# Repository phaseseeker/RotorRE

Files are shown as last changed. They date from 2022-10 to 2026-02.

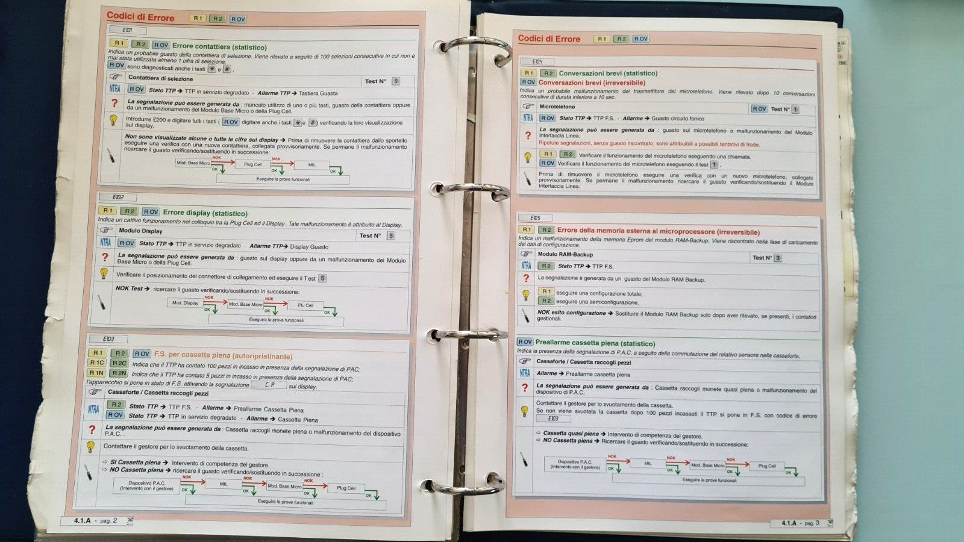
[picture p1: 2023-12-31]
manual/s-l1600 (2).png

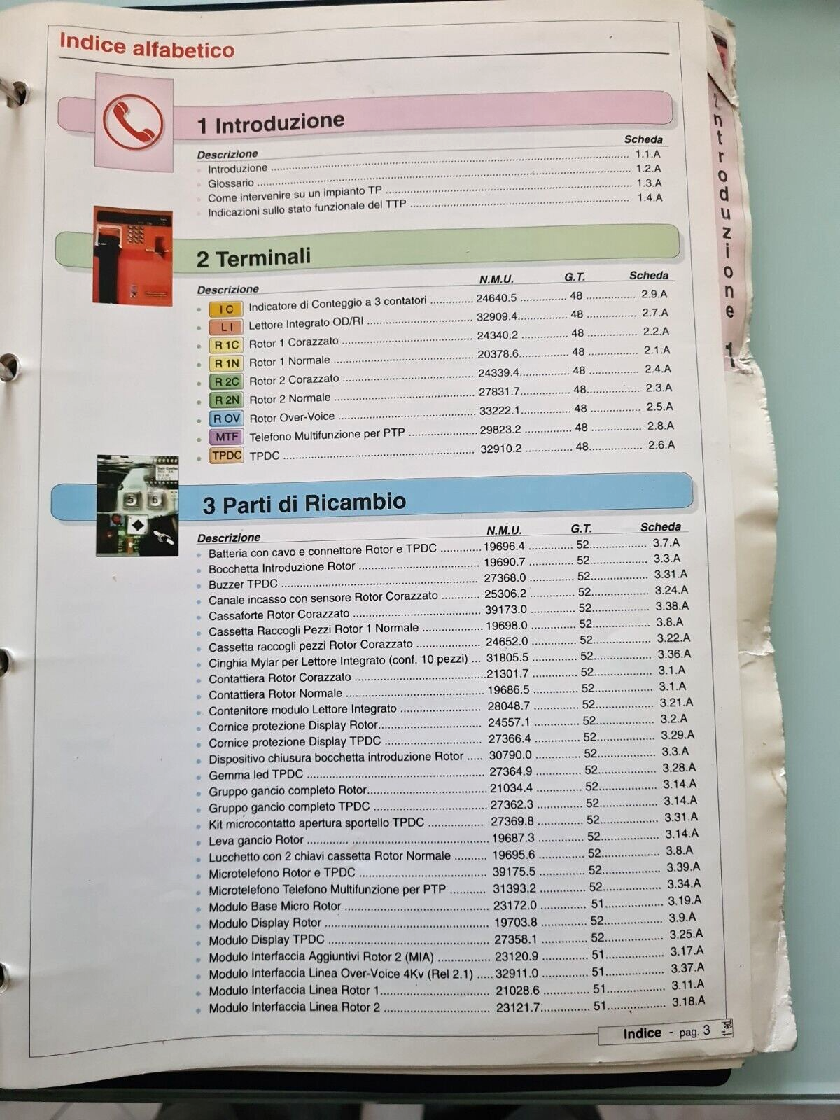
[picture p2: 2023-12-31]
manual/s-l1600 (9).png

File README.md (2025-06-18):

# RotorRE
(versione in italiano più in basso)

Collection of files from my IPM Rotor 2 reverse engineering project
For all the info, see https://hackaday.io/project/181937-reverse-engineering-the-rotor

The "schematics" folder contains schematics for the board I've traced so far. Note that that there are different revisions of some of the boards with minimal differences. The revisions I actually traced are reported in the folders; designators in the files match the designators on the physical board, and as far as I know they should match between revisions.

The "hitachi" folder contains the original manual for the HD6305 processor used in the phone AND the Ghidra module I wrote to decompile the ROMs.

Parts of the original manual can be found in the "manual" folder

There's also some of the pictures I took of the internals in the "pics" folder.

I DO have binary images of the ROMs for the boards I have, both for the phone and for the internal card reader. I won't post them here since it's still technically copyrighted code. All of the phone CPU boards in my possession are equipped with ROM version 1.11 from '91, while my card readers have two different FW revisions. Not 100% of the differences yet. I haven't worked on the newer "OV" revisions board yet and I don't plan to unless I absolutely have to.

-------------------------------------------------------

Collezione di file per il mio progetto di reverse engineering del telefono pubblico italiano Rotor 2 (prodotto da IPM)
La documentazione in ITALIANO è contenuta nei file doc.pdf e documentazione.odt; parte dei manuali ufficiali Telecom/SIP/IPM sono disponibili nella cartella "manual"
Attualmente il progetto è arrivato al punto che è possibile inizializzare il telefono ed utilizzarlo per ricevere/effettuare chiamate, come se fosse un Rotor 1; 
tutte le funzioni "avanzate" quali incasso monete, chiamate con schede ecc non sono ancora disponibili

La cartella "schematics" contiene gli schemi di tutte le schede del Rotor 2 + il lettore di schede ("LIOD") in formato KiCad;
notare che le tre varianti principali del telefono (Rotor 1 "due fili", Rotor 2, Rotor OverVoice) differiscono solo nella scheda di Interfaccia Linea,
mentre le altre schede sono intercambiabili e pressochè identiche. Esiste inoltre una variante solo schede, il Rotor 3 "TPDC", che ha in comune il
solo lettore, ed una variante parecchio rara del Rotor 1 (riconoscibile per il foro della serratura posto in basso a destra); di quest'ultimo sono
disponibili gli schemi originali nella cartella "manual" (in ogni caso le IL dei Rotor 1 e 2 sono abbastanza simili fra loro)
Al momento non ho intenzione di disegnare schemi per le interfaccia linea tipo OV se non assolutamente necessario in quanto sono decisamente più moderne
delle altre e quindi più rognose da analizzare.

La cartella "hitachi" contiene il manuale originale del microcontrollore HD6305 (instruction set Motorola 6805) del telefono, più un modulo per Ghidra.

La cartella "pics" contiene semplicemente alcune foto dell'interno di un Rotor 2.

Sono in possesso delle immagini delle ROM dei micro delle tre varianti del telefono + del lettore (ma non di tutte le revisioni del software), ma NON
le pubblicherò qui dato che tecnicamente si tratta di codice coperto da copyright.

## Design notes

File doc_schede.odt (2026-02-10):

Schede telefoniche

Questo documento descrive nel dettaglio le schede telefoniche prepagate, del tipo a banda magnetica Urmet, rilasciate da SIP e poi Telecom Italia per l’utilizzo con i telefoni pubblici tipo Rotor e G+M.

Premessa

Le informazioni contenute in questo documento sono sia frutto dei lavori precedenti da parte del progetto Magneto (vedi http://magneto.eptousa.altervista.org/) e del progetto “Schedeleaks” (vedi http://schedetelefoniche.org/), che ringrazio, sia di ore di ricerche e di reverse engineering effettuate da me su un lettore di schede originale Urmet tipo LIOD (il lettore utilizzato dai Rotor).

Struttura fisica

Le hanno dimensioni conformi allo standard ISO/IEC 7810 ID-1 (quindi misurano 85,60x53,98mm), con tre importanti differenze:

- Lo spessore è inferiore: 0,35mm contro circa il doppio di una scheda ISO Questo è necessario perché i lettori tradizionali Urmet/IPM sono del tipo “a tamburo” e necessitano di una scheda che sia sufficientemente flessibile per avvolgersi attorno al tamburo gommato del lettore.
- La banda magnetica si trova alla medesima distanza dal centro della carta rispetto ad una scheda ISO, ma è più sottile (circa 8mm) e più corta (anche se esistono schede con lunghezze della banda differenti)
- L’angolo della scheda è preforato e va rimosso prima dell’uso; lo scopo dell’angolo rimovibile è il garantire che una scheda nuova sia effettivamente “vergine” e contenga tutto il suo credito.

Codifica dei dati

Le similarità con le schede “tradizionali” finiscono qui. La codifica dei dati, rimasta per anni un mistero e fonte di grandi curiosità per i phreaker, è infatti completamente nonstandard e proprietaria Urmet.

Un primo indizio ci viene fornito proprio da un brevetto Urmet, codice IT1159459B “Sistema di registrazione e lettura di schede magnetiche valorizzate particolarmente per telefonia pubblica”

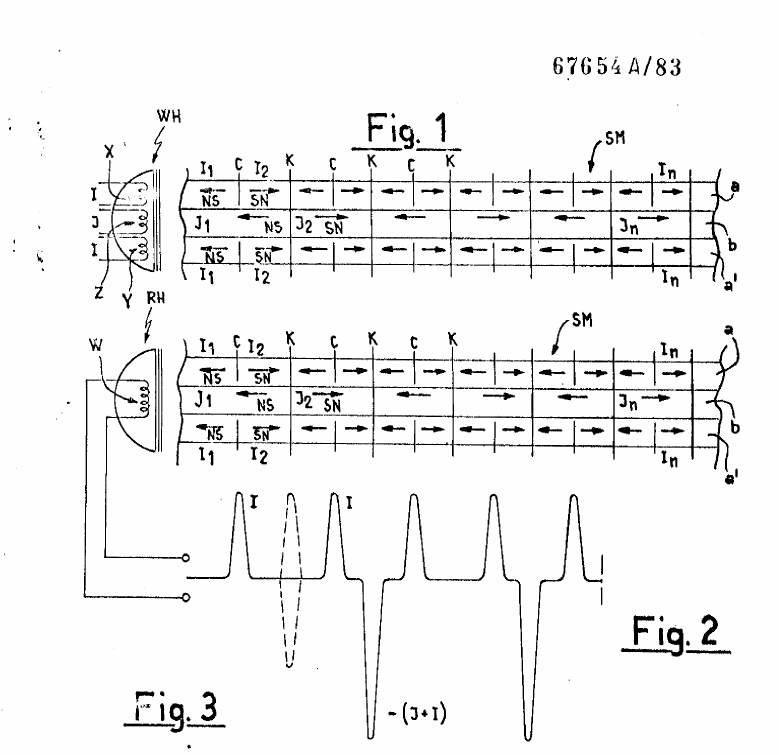
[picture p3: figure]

Come visibile dalla figura, la banda magnetica presenta tre tracce longitudinali:

- Quella centrale costituisce il “clock” della scheda, e permette di sincronizzare il lettore ai dati contenuti
- Le due tracce laterali hanno lo stesso contenuto, e costituiscono i dati effettivamente memorizzati

Questa soluzione, per quanto bizzarra, ha due vantaggi teorici rispetto ad una codifica ISO:

1. La presenza di un clock facilita le operazioni di lettura da parte del lettore, che a questo punto può adattarsi ad un range di velocità di movimento della scheda abbastanza ampio
2. Come da brevetto, dato che testine magnetiche a tre tracce sono sostanzialmente introvabili sul mercato, dovrebbe risultare molto difficile scrivere una scheda contraffatta (nella pratica questo si è rivelato falso, per ragioni non difficili da intuire); la lettura invece è possibile con una normale testina a singola traccia, che restituirà un segnale che è la somma di dati e clock.

Come vedremo più avanti, la codifica effettivamente utilizzata dalle schede in commercio è differente da quanto illustrato nel brevetto ma i due punti fondamentali (banda magnetica a tre tracce, clock e dati separati) rimangono validi e ci aiutano nella decodifica.

Se proviamo a catturare il segnale in uscita dalla testina del lettore, opportunamente amplificato, otteniamo una forma d’onda simile a questa:

Figura 1: Banda magnetica di una scheda "servizi aggiuntivi telefonia"

Notiamo la presenza, come già scoperto anche dai ragazzi del progetto Magneto (e visibile, meno chiaramente, con un lentino magnetico), di una serie di elementi (in ordine da sx):

- Un picco di apertura (rosso)
- La 1a trama (giallo)
- Un picco di separazione (rosso)
- La 2a trama (azzurro) (questa scheda ha una 2a trama incompleta; vedi ulteriori dettagli più avanti)
- La 3a trama (credito, verde)
- Un picco di chiusura (rosso)

Ingrandiamo ora l’inizio dei dati della 1a trama:

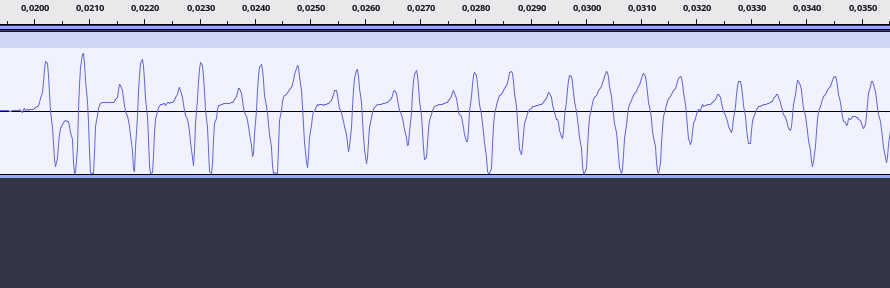
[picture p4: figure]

Figura 2: Prima trama della stessa scheda in fig. 1

Visto così, il segnale non ci dice molto; Avendo a disposizione un lettore originale, però, possiamo ricavare ulteriori informazioni; osserviamo ora i segnali in uscita dal circuito di interfaccia testine (riferiti alla medesima sezione della medesima scheda):

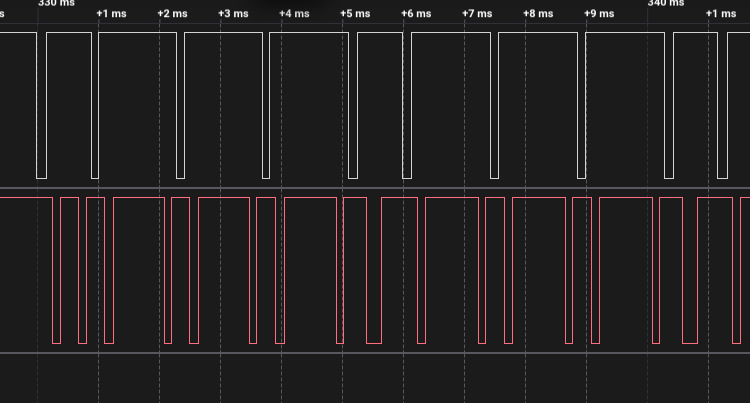
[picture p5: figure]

Figura 3: Inizio della prima trama della scheda in fig.1, separata in clock e dati

La traccia superiore rappresenza il clock estratto dalla scheda; la traccia inferiore invece i dati.

Se seguiamo l’approccio indicato da Schedeleaks, un bit 0 è codificato come un picco sulla traccia dati fra due picchi di clock, mentre un bit 1 è codificato come due picchi; nella seconda immagine quindi i bit rappresentati sono111101110; l’ordine dei dati è big endian.

Confrontando inoltre questi due segnali digitali con la forma d’onda analogica presente sopra, notiamo che dati e clock sono rappresentati tramite picchi con polarità opposta; nel caso specifico della foto il clock corrisponde a picchi positivi mentre i dati a picchi negativi. (la polarità dipende dal modo in cui è collegata la testina; l’aspetto importante è che dati e clock hanno polarità opposte).

I primi due bit contenuti su una scheda sono “speciali”: sono sempre due 1 ed il primo è sempre “corto” (distanza fra i due clock ridotta rispetto ai successivi bit a 1); questi bit NON sono parte dei dati della scheda, ed il lettore misura la durata di entrambi. Sospetto questo sia utilizzato per calibrare la velocità di movimento della scheda.

Analizziamo ora il contenuto delle varie sezioni:

1a trama

Questa trama contiene il numero seriale della scheda telefonica; conosciamo il significato delle singole parti del seriale grazie ai lettori ufficiali SIP (lettore G+M accoppiato ad uno speciale “display”).

La 1a trama è composta da 2 bit speciali + 40 bit di dati:

- I primi due bit, come indicato sopra, sono speciali e non fanno parte del contenuto della scheda
- Byte 0: Checksum, vedi algoritmo più sotto; I primi due bit devono essere sempre 1. Il lettore decodifica questi byte e li memorizza, ma non li invia al Rotor.
- Byte 1: Classe scheda. Intero, unsigned, a 8 bit.
- Byte 2: N° di emissione. Intero, unsigned, a 8 bit. Il numero visualizzato dal lettore corrisponde a (valore del byte + 1)
- Byte 3: N° serie. Intero, unsigned, a 8 bit. Anche qui va aggiunto 1 al valore letto.
- Byte 4 e 5: N° progressivo. Intero, unsigned, a 16 bit (big endian). Anche qui va aggiunto 1 al valore letto.

La verifica del checksum avviene tramite i seguenti passaggi:

1. Si conta il numero totale di bit a ‘1’ all’interno di entrambe le trame escluso il byte di checksum
2. Si calcola quindi il complemento a 1 del valore ottenuto al punto 1 (cioè si fa un NOT bit a bit del valore del contatore)
3. A questo punto si controlla il valore dei bit 7,6 (i due col peso più alto) del checksum letto dalla scheda; questo determina quale di quattro costanti possibili va sommata al valore del punto 2, nello specifico:
  1. Bit 00 → +6
  2. Bit 01 → +5
  3. Bit 10 → +4
  4. Bit 11 → +0
4. Si prende il valore appena ottenuto e si effettua un OR bit-a-bit con la costante 0xC0
5. Il valore appena calcolato deve coincidere con il byte di checksum letto dalla scheda, altrimenti questa viene rifiutata

Il lettore tipo LIOD trasmette sempre il contenuto di questa trama al Rotor, sotto forma di 4 byte (cioè i byte 1-5 della trama). Per la scheda dell’immagine la prima trama è (DD) 1A F1 9C FC

2a trama

Questa trama contiene dati aggiuntivi, utilizzati dal traslatore di centrale (il TRS nella documentazione SIP/Telecom) solo nel caso in cui la scheda riporti del credito.

Il lettore tipo LIOD infatti trasmette il contenuto di questa trama solo per schede non esaurite.

Gli altri documenti sulle schede parlano di due tipi diversi di 2a trama, come visibile sotto (la trama che ci interessa è evidenziata in azzurro):

Figura 4: banda magnetica della scheda di fig.1; notare la 2a trama "spezzata"

Figura 5: banda magnetica di una scheda "dilungatevi pure" con 2a trama "lunga". Forma d'onda presa dai file del progetto Magneto

Come possiamo notare dalle figure, le due schede hanno seconde trame con un numero di bit diverso; sia gli autori del progetto Magneto che quelli del progetto Schedeleaks ipotizzano che si tratti di tipi diversi di scheda telefonica, tuttavia la spiegazione è diversa.

Se proviamo a sovrapporre le bande magnetiche delle due schede, notiamo che in entrambi i casi la lunghezza della trama è simile, ma nel caso della trama “spezzata” sembra che sia stata rimossa una porzione di banda; questo perché è esattamente quel che è accaduto alla prima scheda!

Analizzando il comportamento del lettore, infatti, si scopre che quando una scheda raggiunge 0 unità di credito (come nel caso della prima scheda), il lettore stesso procede a distruggere parte della 2a banda, in modo da essere completamente sicuri che la scheda sia completamente inutilizzabile e non possa essere ricaricata alterando la sezione credito; si tratta di quello che i nostri amiconi della Urmet chiamano obliterazione magnetica.

Una 2a trama intatta contiene esattamente 32 bit di dati.

Il LIOD invia questi 4 byte al telefono solo nel caso in cui la scheda risulti carica; per una scheda con 2a trama obliterata, la lettura si interrompe una volta rilevato il gap dopo i primi 3 bit di dati, e vengono trasmessi al Rotor quattro byte vuoti (0x00)

3a trama: credito

Questa trama contiene semplicemente il credito della scheda, in unità di valore 100L o 0,10€. La lunghezza di questa sezione è variabile, in quanto ciascuna unità è codificata semplicemente come un bit 1, e la banda è sempre terminata con un ulteriore bit 1. Il credito, quindi, è pari al numero di bit memorizzati in questa sezione – 1.

Man mano che la scheda viene utilizzata, il lettore procede a cancellare parti di questa sezione per alterarne il valore.

N.B: Il valore di credito memorizzato sulla scheda è “preso per buono” solamente nei telefoni tipo G+M; i telefoni tipo Rotor (e Digito) inviano seriale + 2a trama + credito letto dalla scheda al traslatore di centrale, il quale consulta un database remoto con i dati di credito delle schede e comunica al telefono eventuali incongruenze. Pertanto, quando queste schede erano “in servizio”, anche se fossimo riusciti a riscrivere il contenuto della sezione credito (cosa che è stato dimostrato essere possibile), comunque non sarebbe stato possibile ingannare il telefono.

In ogni caso non è possibile riutilizzare una scheda che sia completamente scarica, in quanto la 2a banda risulterebbe danneggiata.

Il LIOD trasmette il credito al telefono sotto forma di un singolo byte.

La trasmissione completa LIOD → Rotor ha quindi la seguente struttura:

03 PP PP PP PP SS SS SS SS CC CK

Dove:

- 03 è il tipo di scheda (→ “Prepagata telefonica”)
- PP identifica un byte della 1a trama
- SS identifica un byte della 2a trama
- CC è il credito (in unità)
- CK è il checksum generato dal lettore. Si tratta dello XOR di tutti i byte precedenti (NON è il checksum contenuto sulla banda magnetica!)

Extra: carte di credito telefoniche

Una carta di credito telefonica (CTC) è semplicemente una carta di credito rilasciata da SIP/Telecom ed utilizzata esclusivamente per telefonare. Queste carte richiedono un PIN di 4 cifre (indicato come “codice utente”), verificato sempre dal traslatore, per autorizzare la transazione.

In questo caso la codifica utilizzata è quella standard ISO, anche se la quantità di dati presente è inferiore rispetto ad una carta di credito “commerciale”.

Esempio del contenuto di una scheda: ;977887:8739:8239? (scheda di test SIP)

Il tipo scheda associato ad una CTC è 04.

Il LIOD invia sempre 11 byte, di cui il primo è appunto 04 e l’ultimo è il checksum XOR.

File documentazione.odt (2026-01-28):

Documentazione Rotor

SCL1054-V4

Tre funzioni: port expander (1 porta bidirezionale, 2 solo output + 1 singolo pin per selezione banco ROM), espansione RAM (192 byte extra) e logica decodifica indirizzi.

La RAM è mappata nel range di indirizzi 0x0144-0x1FF ed è accessibile come fosse RAM interna al micro

Le porte I/O sono controllate tramite 5 registri mappati in memoria (i nomi corrispondono a quelli usati nel disassembly del codice):

1. SCL_DATA: bidirezionale; registro “direzione” @ 0x0023 (bit a 1 → il pin è configurato come output), registro dati @ 0x0022. Porta a 8 bit, prende il nome di “SCL_DATA” perché, come visibile dagli schemi, funge da bus dati esterno per le varie periferiche collegate al SCL
2. SCL_ADDR: 8 bit, output only; registro dati @ 0x0020. Pilota, tramite U5 e U6 il bus indirizzi di ROM/RAM esterne. I bit 7, 6, 5, 3 sono multiplexati con i segnali di controllo dei tre solenoidi + il reset del LCD (vedi schema)
3. SCL_CTRL: 8 bit, output only; registro dati @ 0x0021. Collezione di vari output, controlla lo schema per più dettagli. (Nello schema, i pin di questa porta sono indicati come SCL-nn, dove nn è il numero del pin nel package del SCL; SCL-43 corrisponde al bit 0, e gli altri seguono in ordine crescente)
4. SCL_BANK: 1 bit, output only; Pilota A14 sulla ROM: permette quindi di scegliere fra i due banchi di codice.

Tutta la logica di decodifica degli indirizzi di memoria per le porte, la RAM e la ROM, è contenuta nell’SCL, che procede a selezionare automaticamente i circuiti corrispondenti.

Comunicazione dati

Il Rotor comunica con il “traslatore di centrale” (di seguito indicato semplicemente come TRS) utilizzando la linea as/bs, dalla quale viene anche prelevata la corrente necessaria per l’alimentazione del circuito caricabatterie.

Le comunicazioni in direzione TRS→Rotor avvengono invertendo la polarità della linea di segnalazione (polarità normale: filo a NEGATIVO, filo b POSITIVO; N.B: i sistemi telefonici sono a TERRA POSITIVA, quindi è il filo B ad essere a terra) in modo temporizzato; queste inversioni vengono rilevate dal telefono mediante il fotoaccoppiatore OP3.

Le comunicazioni in direzione Rotor→TRS avvengono invece variando la corrente assorbita dal telefono sulla linea di segnalazione: quando il telefono desidera trasmettere, il fotoaccoppiatore OP4 viene attivato, cortocircuitando i tre transistor T5,T6,T7 e aumentando la corrente di linea; il TRS rileva questa variazione mediante un proprio fotoaccoppiatore inserito in serie alla linea.

Nota: questo tipo di comunicazione è stato “ereditato” dal precedente telefono modello G+M, tant’è che nel brevetto di uno dei TRS compatibili con il Rotor il circuito di interfaccia è indicato con il nome di SGM (“Sonda Gettone+Moneta”)

Esistono due diversi “protocolli” di comunicazione, utilizzati in situazioni differenti:

1) Protocollo “Telegrafico”:

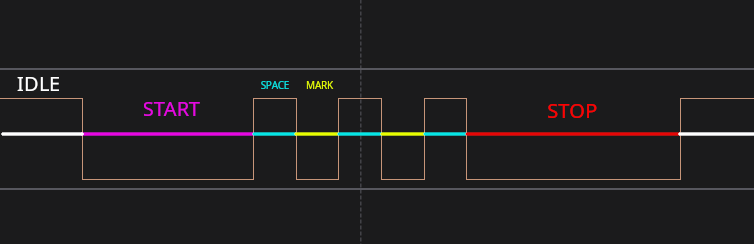
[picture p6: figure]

Si tratta del più semplice dei due, ed è simile alla selezione decadica; una comunicazione di questo tipo si può analizzare dividendola in 5 fasi, come visibile nell’immagine.

N.B: I segnali sono mostrati nella forma in cui appaiono sulle porte di I/O del microcontrollore. I segnali in entrambe le direzioni (Rotor→TRS e TRS→Rotor) assumono in questo caso lo stesso aspetto in termini di forme d’onda.

Per i segnali provenienti dal TRS, il livello logico ALTO corrisponde a polarità normale, mentre quello basso a polarità invertita; per i segnali provenienti dal Rotor, il livello ALTO corrisponde a OP4 off e quindi corrente di linea minima (la sola corrente di alimentazione), mentre quello basso corrisponde a OP4 on e corrente massima

A. IDLE: linea “a riposo”
B. START: impulso di inizio comunicazione. Per le trasmissioni provenienti dal Rotor, ha due possibili durate; Per le comunicazioni in direzione TRS→Rotor, diversi valori per lo start sono ammessi, vedi più sotto per i dettagli
C. SPACE, MARK: In seguito all’impulso di start, i dati da trasmettere sono inviati cifra (decimale) per cifra sotto forma di una serie di impulsi negativi (mark), lunghi 10ms, separati da pause della stessa lunghezza (space). La cifra trasmessa è pari al numero di mark + 1; lo 0 è trasmesso sotto forma di 10 impulsi.
D. STOP: impulso di fine trasmissione. Ha sempre durata 50ms in direzione Rotor→TRS, mentre in direzione opposta sono ammesse due differenti lunghezze che, di nuovo, cambiano il modo in cui vengono interpretati i dati trasmessi; vedi sotto per i dettagli

Tipi di trasmissioni telegrafiche

DIREZIONE TRS → Rotor

1) Comando: start 50ms, stop 50ms

Il telefono interpreta il numero inviato come indice del comando da eseguire. Sono supportati 7 comandi, descritti più avanti in questo documento. Se il numero di impulsi risulta > 7, la trasmissione viene semplicemente ignorata

2) Addebito monete: start 35ms, stop 50ms

Comando di “addebito” per il credito relativo alle monete (il credito “monete” ed il credito “carte” sono gestiti in modo completamente separato all’interno del software del telefono)

Il telefono sottrae una somma pari a cifra_inviata*100L al credito e visualizza il nuovo credito

NOTA: Per le transazioni a monete, è sempre necessaria una successiva conferma di incasso, altrimenti il telefono restituisce la moneta.

NOTA 2: Prima di inviare un comando di addebito, è necessario inviare almeno una richiesta credito al telefono, vedi l’elenco comandi più in basso, altrimenti l’incasso non andrà a buon fine

3) Addebito schede: start 20ms, stop 50ms

Comando di “addebito” per le schede telefoniche. Il telefono sottrae una somma pari a cifra_inviata*100L al credito, visualizza il nuovo credito e aggiorna il credito sulla banda magnetica della scheda.

NOTA: In questo caso non è necessaria una conferma di incasso, il lettore integrato cancella il credito non appena il comando è ricevuto.

NOTA 2: Se il telefono riceve questo comando quando non è presente una scheda e/o non è presente nessun lettore, la cifra ricevuta viene visualizzata sul LCD, fino ad un massimo di 4 cifre contemporaneamente (10 impulsi = “0”; i valori da 11 a 15 corrispondono a simboli)

4) Telereset Rotor: start 700ms, stop 50ms

Permette al TRS di reinizializzare il Rotor; Il telefono si pone in FS e attende una nuova configurazione.

NOTA: non si tratta di un vero e proprio reset, in quanto il software si limita a cancellare la configurazione in memoria

5) Possibile telereset LIOD: 70ms < start < 700ms

Alla ricezione di questa trasmissione, il telefono resetta una serie di variabili relative allo stato del LIOD; ulteriori indagini sono necessarie

6) Incasso monete: start 50ms, stop 90ms

Comando di incasso/conferma addebito per le monete: conferma la riduzione del credito effettuata dai comandi di addebito. La cifra inviata può avere valore 1-3, altrimenti il comando viene ignorato. Dalle prove effettuate sembra che solo il valore 2 venga accettato.

NOTA: Come specificato per il comando di addebito, l’incasso può avvenire solo se il credito (inteso come il numero ed il tipo di monete inserite) è stato inviato dal telefono al TRS

DIREZIONE ROTOR → TRS

1) Comunicazione generica: start 40ms, stop 50ms

Utilizzata dal telefono quando deve inviare informazioni al TRS, sia che si tratti di risposte a comandi (eccetto comando “richiesta credito”) sia che si tratti di allarmi (trasmissioni “spontanee”). In questo caso il telefono invia una singola cifra.

2) Conferma incasso: start ??, stop 50ms

Come sopra, ma utilizzata per confermare la ricezione con successo del comando di incasso. La cifra inviata dal telefono corrisponde a quella che era stata inviata dal TRS all’interno del comando di incasso. In caso di incasso non riuscito, non si riceve nessuna risposta dal telefono.

NOTA: A differenza dei telefoni precedenti, nel Rotor 2 la conferma di incasso NON avviene necessariamente quando la moneta transita davanti al sensore posto alla fine del canale di incasso; è sufficiente che il telefono abbia registrato la richiesta per ottenere la conferma incasso.

3) Credito: start 40ms ripetuti (vedi foto), stop 50ms

Tipo di trasmissione utilizzato per comunicare al TRS il credito IN MONETE inserito nel telefono; si tratta di tre cifre inviate una di seguito all’altra, separate da uno “start” da 40ms inviato dopo gli impulsi della 1a e 2a cifra.

La 1a cifra ha valore 200L, la 2a ha valore 100L, la 3a è sempre 0.

NOTA: Il telefono non invia mai più di 14 impulsi per la 1a cifra e 6 per la 2a.. In caso di credito superiore a 3400L, quindi, il valore ricevuto può non rispecchiare il credito effettivamente presente nel tamburo.

NOTA 2: Il telefono risponde al comando di richiesta credito solamente la 1a volta che lo riceve all’interno di una conversazione. Per le monete inserite successivamente, il telefono invia in modo spontaneo altre 3 cifre che indicano il credito aggiunto (quindi non il totale, ma solo quello relativo alle monete appena inserite).

4) Segnalazioni “spontanee”/allarmi: start 40ms, stop 50ms

Il formato è esattamente lo stesso delle comunicazioni generiche, ma in questo caso si tratta di dati inviati dal telefono senza che il TRS invii alcuna richiesta. Si tratta anche qui di una “cifra” sola, e i valori noti sono:

- 10 → Cornetta riappesa
- 11 → Interruzione colloquio con lettore interno (guasto MIA, rimozione lettore ecc)
- 12 → Sconosciuto
- 13 → Cassaforte aperta (solo Corazzato)
- 14 → Cassetta monete rimossa (solo Corazzato)
- 15 → Perdita linea voce

2) Protocollo “pseudo-BPSK”

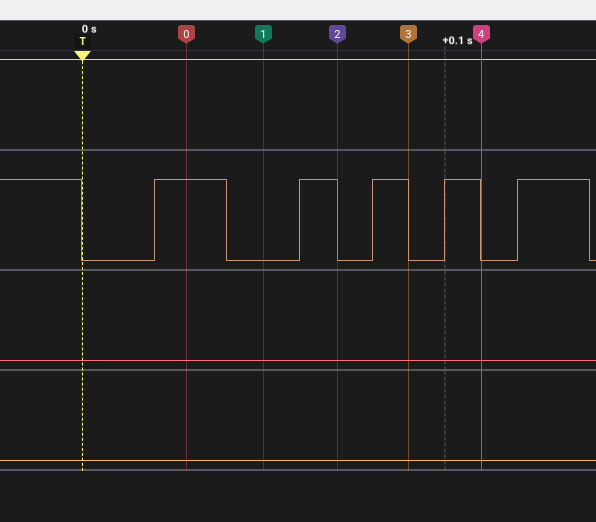
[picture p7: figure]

Si tratta del secondo protocollo supportato, utilizzato principalmente per inviare i dati di carte di credito (telefoniche e/o “commerciali” di tipo Diners e AMEX) e schede telefoniche prepagate.

In questo caso la trasmissione è di tipo binario e, da quanto determinato finora, sembra sia utilizzata solo in direzione Rotor → TRS

La trasmissione con questo protocollo inizia sempre con uno start, composto da un picco negativo lungo 20ms seguito da 10ms di pausa (nella foto, è la parte fra il cursore T ed il cursore 0), seguito poi dai dati binari.

Tali dati sono codificati con quella che possiamo definire codifica pseudo-BPSK (Binary Phase Shift Keying):

- Un bit a 0 è codificato come 10ms a livello alto seguiti da 10ms a livello basso
- Un bit a 1 è codificato come 10ms a livello basso seguiti da 10ms a livello alto

Nella foto di esempio, i primi 4 bit trasmessi sono 0111 (→ 0x7)

Comunicazione lettore-Rotor:

Come molti aspetti di questo telefono, la comunicazione fra lettore di schede interno (d’ora in poi indicato come LIOD, “Lettore Integrato a Obliterazione Durante”, come viene chiamato nei manuali) avviene in modo assolutamente non standard.

A livello elettrico, la comunicazione avviene tramite due linee unidirezionali; d’ora in poi indicheremo come TXD la linea che sposta dati in direzione Rotor→LIOD e RXD quella in direzione opposta

(N.B: nello schema le linee sono indicate dal punto di vista del LIOD, quindi invertite rispetto a questo documento).

Un’ulteriore linea viene utilizzata dal telefono per rilevare la presenza del lettore; un resistore di pull’up all’interno del lettore fa sì che questa linea sia a +5V con lettore presente, 0 altrimenti.

Nota: La scheda di interfaccia lettore (indicata d’ora in poi come MIA, “Modulo Interfaccia Aggiuntivi”, di nuovo per coerenza con il manuale) è decisamente più complicata di quanto necessario in quanto è concepita per supportare due differenti tipi di lettore.

Non sappiamo di per certo quale sia il secondo lettore teoricamente supportato (la documentazione lo indica semplicemente come lettore di debito, ma il manuale, almeno la versione più recente, indica che l’unico lettore effettivamente utilizzato è il LIOD); un’ipotesi è che si tratti del mitico “lettore azzurro”, un lettore di schede telefoniche progettato per l’uso con il G+M e prodotto in numeri molto ridotti, ma non dispongo di un lettore per confermare questa ipotesi e non sappiamo nemmeno se il codice lato Rotor sia completo e funzionante.

Un ulteriore pin del microcontrollore viene utilizzato per scegliere fra i due e l’interfaccia per l’altro lettore utilizza dei pin in più, ma per semplicità ignoreremo completamente questa prossibilità.

Tutte le foto e le descrizioni da qui in poi fanno riferimento ai segnali come visti dal microcontrollore del Rotor. In ogni caso, una volta che il telefono è inizializzato ed ha rilevato correttamente il lettore, il MIA passa il segnale RXD (e DET) inalterato dal lettore al telefono, mentre TXD viene invertito.

Il successivo Rotor O.V. fa a meno del MIA e controlla il lettore direttamente dal micro.

Nota 2: Esistono diverse revisioni del LIOD, l’ultima delle quali viene indicata nel manuale come LI O.D./R.I (“Lettore Integrato a Obliterazione Durante e Restituzione dalla bocchetta di Ingresso). Il manuale fornisce ulteriori dettagli a tale proposito; l’interfaccia rimane la medesima.

Il protocollo di comunicazione non è né RS232 standard, né tanto meno una delle interfacce sincrone “comuni” quali SPI, I2C ecc.

Il Rotor agisce sempre come master della comunicazione, in quanto il lettore non può iniziare una comunicazione ma solo inviare dati quando clockato dal telefono.

Vediamo un esempio di una comunicazione:

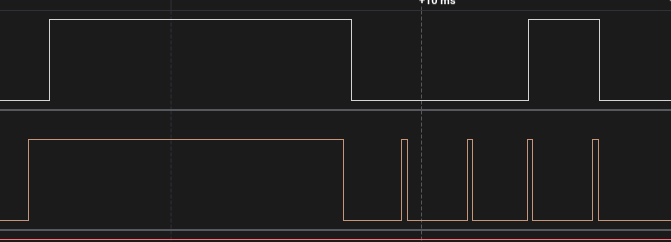
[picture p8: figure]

In bianco RXD, in arancio TXD; TXD, come intuibile dall’immagine, ha la doppia funzione di trasportare comandi in direzione Rotor→LIOD e di clockare il lettore per la risposta.

La comunicazione si articola in due fasi:

1. Comando: (sempre proveniente dal telefono e destinato al lettore) si tratta del primo impulso positivo; I differenti comandi sono codificati variando la lunghezza di tale impulso. Il firmware del Rotor 2 versione 1.4, l’ultima rilasciata, supporta 10 comandi; il lettore è in grado tuttavia di riconoscerne un numero più ampio (potrebbero essere comandi di test/comandi avanzati supportati solo dal Rotor OV). Il lettore risponde semplicemente pilotando RXD allo stesso livello di TXD (salvo casi particolari indicati più avanti)
2. Clock + risposta: Il telefono a questo punto procede a clockare il lettore in modo da leggere la risposta inviata da quest’ultimo. Ciascuno dei quattro impulsi di clock inviati dal telefono ha entrambi i fronti attivi: RXD viene campionato quindi due volte per impulso, una sul fronte di salita ed una sul fronte di discesa, con un piccolo delay fra il fronte di clock ed il campionamento per consentire al lettore di pilotare RXD al valore appropriato. Gli impulsi di clock sono lunghi circa 250 us, separati fra loro e dal comando da una pausa di 2,5 ms.

Nella trasmissione di esempio, il telefono invia il comando “di idle” (comando che viene inviato continuamente dal telefono per segnalare al lettore che è tutto ok e può accettare schede), mentre il lettore risponde con 0x07.

Esiste una modalità di trasmissione particolare, che chiameremo burst mode, utilizzata per la lettura delle schede e per alcuni comandi particolari. In questa modalità, dopo aver letto il primo byte di risposta al comando, il Rotor non riporta la linea a riposo ma, ad una distanza circa 5 ms (il timing non è critico: pause molto più lunghe sono accettabili), ripete altri 4 clock per un totale di 40 impulsi, leggendo cioè 10 byte oltre quello iniziale.

La durata del burst è fissa a 10 byte.

Esiste, come accennato sopra, un caso particolare: nel caso in cui il lettore sia occupato a leggere una scheda, si comporta come visibile al centro della foto seguente:

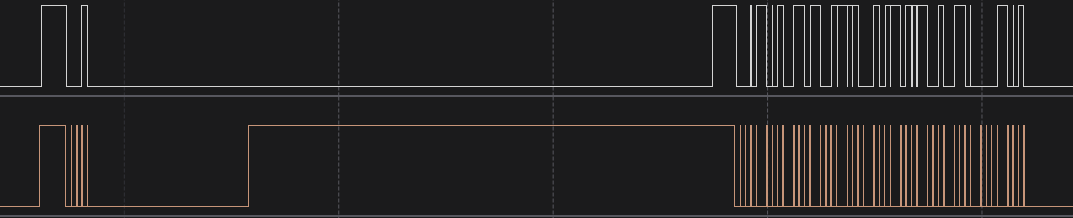
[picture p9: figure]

Il lettore, cioè, rilevato l’inizio del comando, non risponde portando RXD a livello alto (quasi) istantaneamente, come di consueto, ma lo fa solo una volta terminata la lettura. In questo caso la durata del comando è misurata a partire dal rising edge di RXD

Una lettura avvenuta con successo porta ad una differente risposta al comando di IDLE (più dettagli sulle risposte in seguito), seguito dai dati delle schede trasmessi in burst mode.

Comandi e risposte lettore:

Le durate dei comandi, per il firmware lettore v3.1 04/05/93, sono:

- 0ms < len <= 2ms CMD0: NOP
- 2ms < len <= 17ms CMD1: Stato lettore/IDLE
- 17ms < len <= 32ms CMD2: Possibile comando di addebito
- 32ms < len <= 47ms CMD3: Sconosciuto
- 47ms < len <= 62ms CMD4: Espulsione scheda
- 62ms < len <= 87ms CMD5: Modalità Rotor (necessario per il normale funzionamento)
- 87ms < len <= 102ms CMD6: Reinvia dati scheda*
- 102ms < len <= 117ms CMD7: Richiesta dati extra CCC *(ulteriori 10 byte)
- 117ms < len <= 132ms CMD8: Sconosciuto
- 132ms < len <= 147ms CMD9: NOP
- 147ms < len <= 162ms CMD10: Sconosciuto
- 162ms < len <= 177ms CMD11: Sconosciuto
- 177ms < len <= 195ms CMD12: Sconosciuto
- 195ms < len <= 207ms CMD13: NOP
- 207ms < len <= 222ms CMD14: Sconosciuto
- 222ms < len <= 237ms CMD15: Sconosciuto, possibile reset errori meccanica.
- 237ms < len <= 252ms CMD16: Richiesta versione firmware*
- len > 252ms NESSUN COMANDO

I comandi seguiti da un asterisco richiedono l’uso del burst mode. I comandi indicati come NOP non hanno effetto.

Ulteriori dettagli in seguito:

- CMD4: Espulsione scheda. Espelle un’eventuale CTP trattenuta nell tamburo del lettore. Per le CC (commerciali o telefoniche) è necessario inviare un comando di espulsione prima di poter leggere un’altra scheda, nonostante le CC non siano fisicamente trattenute dal lettore.
- CMD5: Modalità “Rotor”. Non si sa quale sia la modalità di default, ma i dati delle schede appaiono corretti solo dopo aver eseguito questo comando.
- CMD6: Ripetizione dati scheda. Il telefono reinvia i primi 10 byte del buffer schede, oppure 10 byte nulli se non c’è nessuna scheda presente. Richiede burst mode.
- CMD7: Richiesta ulteriori dati CCC. Una carta di credito “commerciale” (Diners/AMEX nello specifico, ma il lettore accetta qualsiasi scheda ISO) contiene più di 10 byte di dati; questo comando permette di richiedere gli ulteriori 10 byte. Richiede burst mode, NON contiene checksum
- CMD16: Richiesta versione firmware lettore. Invia 10 byte in burst mode, codificati BCD; i primi 2 corrispondono alla revisione software (es: 0x03 0x01 → 3.1), i successivi tre la data di rilascio (0x04 0x05 0x93 → 4/5/1993). Termina con un checksum XOR dei 10 byte precedenti (risposta al comando + 10 byte di dati)

Analizziamo ora le risposte. È importante notare che per risposta si intende il byte inviato dal lettore appena ricevuto il comando; per i comandi che fanno uso di burst mode, quindi, i byte ricevuti sono 1+10, cioè 1 di risposta + 10 di dati.

Le risposte, almeno per questa versione del FW, sono univoche: quindi ciascuna risposta è specifica ad un determinato comando.

Risposte conosciute:

- 0x07 Lettore OK. Inviata dal comando di richiesta stato per confermare che il lettore è funzionante e pronto.
- 0x03 Seguono dati CTP. Indica la corretta lettura di una scheda telefonica prepagata; inviato in risposta a CMD1, attiva burst mode ed è seguito da 10 byte nel formato PP PP PP PP SS SS SS SS CC CK, cioè 4 byte della 1a trama + 4 byte della 2a trama + 1 byte credito (in unità) + 1 byte checksum che è lo XOR dei 10 precedenti (quindi incluso lo 0x3). La 2a trama è pari a una serie di 0x00 se la scheda è scarica; ulteriori dettagli nel documento sulle schede
- 0x04 Seguono dati CTC. Indica la corretta lettura di una carta di credito telefonica; inviato in risposta a CMD1, è seguito da 9 byte di dati della banda magnetica + 1 byte di checksum, che è di nuovo lo XOR dei 10 precedenti.
- 0x11 Seguono dati CCC. Inviato come risposta a CMD1, indica la corretta lettura di una CCC (Carta di Credito Commerciale) inserita dall’utente. Attiva burst mode ed è seguita da 10 byte di dati letti dalla banda magnetica e nessun checksum. Per una CCC è necessario richiedere separatamente gli altri 10 byte di dati, vedi sopra.
- 0x0A Richiesta espulsione ricevuta. Indica la ricezione del CMD4. Per una CTP NON è sufficiente a garantire che la scheda sia stata meccanicamente espulsa dal tamburo.
- 0x0C Modalità Rotor attivata. Risposta al CMD5, conferma l’esecuzione del comando.
- 0x0E Seguono dati extra CCC. Inviata come risposta al CMD7, provoca l’attivazione del burst mode; è seguita da 10 byte di dati della scheda. Come specificato prima, per le CCC NON c’è checksum
- 0x13 Segue versione FW. Inviata come risposta al CMD16, attiva burst mode ed è seguita da 9 byte di versione + 1 di checksum, che è 0x13 XOR i 9 byte successivi
- 0x47 CTP espulsa. Conferma l’espulsione meccanica di una CTP; inviato in risposta a CMD1, può essere inviato anche senza che il telefono abbia richiesto l’espulsione della scheda, come nel caso di una scheda scarica o non valida.
- 0xEE Risposta a CMD15, conferma l’esecuzione del comando.

Sequenza di boot del telefono:

Il telefono, per funzionare correttamente, richiede due cose:

1. Batteria tampone principale (6V piombo) sufficientemente carica.
2. Configurazione esterna e contatori gestionali (contenuti nella RAM sulla board “RAM esterna”) validi

La batteria tampone della RAM esterna, che consente al telefono di mantenere configurazione esterna e contatori gestionali memorizzati anche con batteria tampone principale scarica, non è strettamente necessaria per il funzionamento del telefono.

Se la condizione numero 2 è verificata, il telefono può essere avviato in modalità normale (entrambi i dipswitch accanto al display su off) semplicemente premendo reset; terminato il boot, il telefono visualizza F.S. (con LED di “fuori servizio” spento) e si pone in attesa della configurazione remota dal TRS

Altrimenti, se i dati di configurazione non sono validi (ad es. telefono con batterie scariche appena rimesso in servizio), è necessario avviare il telefono con il microswitch di configurazione (il sx, vedi manuale) in posizione ON; questo riscriverà la configurazione in RAM.

Se, inoltre, i contatori gestionali (totale monete in cassaforte ecc) risultano non validi, è necessario avviare il telefono tenendo premuto (dal reset fino all’avvio completo) il pulsante del gestore, che è il pulsantino posto all’interno dello scomparto della cassaforte, visibile con cassetta rimossa.

Sequenza di configurazione remota:

Il telefono, dopo ogni boot avvenuto con successo, si pone in F.S. in attesa della configurazione remota; la procedura in questione è piuttosto semplice, ed è visibile nell’immagine seguente

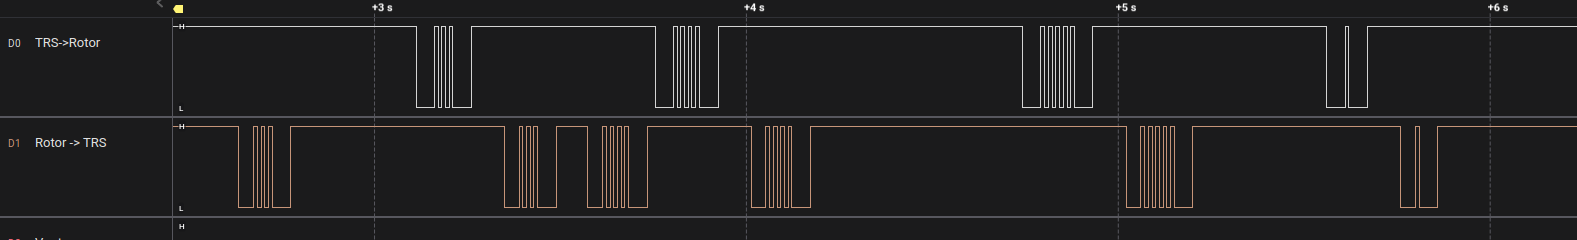
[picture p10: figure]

(riferita ad un telefono con LIOD installato e funzionante).

La procedura prevede la seguente sequenza (tutta eseguita usando il metodo di configurazione telegrafico):

1. Il telefono invia un 3 (prima cifra dello “stato lettore” visualizzato sul display all’avvio, cioè “30”, “33” o “34”, vedi manuale)
2. Il TRS risponde con un 3
3. Il telefono ripete il 3 precedente, quindi invia subito la seconda cifra dello stato lettore (in questo caso 4, lettore OK); Se il lettore è assente (“30” visualizzato sul display all’avvio), questo passaggio ed i due successivi vengono ignorati
4. Il TRS risponde ripetendo l’ultima cifra ricevuta e solo l’ultima (qui un 4)
5. Il telefono ripete la cifra appena ricevuta dal TRS (di nuovo 4)
6. Il TRS ora invia 5 (valore fisso hardcoded)
7. Il telefono risponde 5
8. Il TRS invia 1 (di nuovo un valore fisso)
9. Il telefono risponde 1
10. Il TRS invia quindi, una per una, le tre cifre corrispondenti al valore in lire del gettone telefonico (lo 0 è inviato con 10 impulsi); dopo ogni cifra il telefono risponde reinviando la cifra appena ricevuta al TRS.
11. La procedura di configurazione è ora conclusa ed il telefono è ora funzionante

Nota 1 sul punto 10: la prima cifra del costo del gettone non può essere 0

Nota 2 sul punto 10: a causa di un bug del codice, anche se il telefono può teoricamente accettare qualsiasi valore per le ultime due cifre del costo gettone (es: 123 lire, 488 lire ecc), solo valori multipli di 100 sono effettivamente validi (nello specifico, le ultime due cifre sono salvate in memoria, ma in diversi punti il codice è scritto partendo dal presupposto che il costo sia multiplo di 100 lire e quindi tali cifre sono ignorate)

Una volta terminata la configurazione iniziale, il telefono risulta funzionante e non necessita di ulteriori comunicazioni col TRS per essere utilizzato come un normale telefono. Si comporta sostanzialmente come un Rotor 1: non incassa monete, ma permette di effettuare e ricevere telefonate. Per le altre funzioni (incasso monete, telefonate con schede ecc) è necessario inviare uno o più dei comandi elencati di seguito:

Comandi TRS:

Informazioni note al momento:

- 1 → Lampeggio display. Possibilmente usato come “avviso ottico fine incasso” come per manuale.
- 2 → Conferma validità scheda telefonica; inviato dal TRS dopo aver ricevuto seriale+credito della scheda telefonica per confermare la sua validità e la correttezza del credito contenuto sulla manda magnetica. Nessuna risposta dal telefono.
- 3 → Azzeramento credito schede. Azzera il credito memorizzato dal telefono per quanto riguarda le schede (il credito per le schede e per le monete sono memorizzati separatamente). Se è presente una scheda nel lettore, questa viene espulsa senza alterare la banda magnetica
  Nessuna risposta dal telefono
- 4 → Azzeramento addebiti schede. Azzera eventuali addebiti per le schede che sono stati ricevuti dal telefono ma non processati.
- 5 → Richiesta credito monete. Il telefono invia il credito presente (vedi sopra per il formato)
- 6 → NOP. Al momento non si conoscono ulteriori effetti.
- 7 → Richiesta errori. Il telefono può rispondere con:

1 → Tutto ok.

3 → Guasto sezione monete

4, 5, 9 → Sconosciuti. Probabilmente errori relativi al LIOD.

NOTA: Per ragioni ignote, i codici di errore riportati sopra (incluso quello relativo alla sezione monete) vengono trasmessi SOLO se il lettore è presente. Un telefono privo di lettore risponde sempre “1” anche con sezione monetaria guasta.

La ricezione di un qualsiasi comando provoca un interrupt, eventualmente “svegliando” il micro dallo stato di standby. In presenza di un FS (non irreversibile) attivo, il telefono effettua un autotest.

Se il Rotor riceve un comando in chiamata, quando la cornetta viene riappesa il telefono trasmette 10 (vedi sezione “allarmi” più sopra per ulteriori segnalazioni spontanee)

Note varie:

Importante: se il lettore legge ed accetta una scheda prepagata (quindi una scheda leggibile e con credito != 0), questa viene trattenuta dal telefono in attesa di risposta dal TRS. Per riottenere indietro la scheda NON resettare il telefono: questo ne causa la cancellazione!! (come misura di sicurezza contro truffe con le schede). Il metodo corretto è di inviare un 3 da un TRS simulato, oppure disconnettere la linea telefonica di segnalazione, ed aspettare poi che il telefono invii al LIOD il comando di espulsione scheda.

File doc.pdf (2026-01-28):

# Documentazione Rotor

SCL1054-V4

Tre funzioni: port expander (1 porta bidirezionale, 2 solo output + 1 singolo pin per selezione banco ROM), espansione RAM (192 byte extra) e logica decodifica indirizzi.

La RAM è mappata nel range di indirizzi 0x0144-0x1FF ed è accessibile come fosse RAM interna al micro

Le porte I/O sono controllate tramite 5 registri mappati in memoria (i nomi corrispondono a quelli usati nel disassembly del codice):
1. SCL_DATA: bidirezionale; registro “direzione” @ 0x0023 (bit a 1 → il pin è configurato come output), registro dati @ 0x0022. Porta a 8 bit, prende il nome di “SCL_DATA” perché, come visibile dagli schemi, funge da bus dati esterno per le varie periferiche collegate al SCL
2. SCL_ADDR: 8 bit, output only; registro dati @ 0x0020. Pilota, tramite U5 e U6 il bus indirizzi di ROM/RAM esterne. I bit 7, 6, 5, 3 sono multiplexati con i segnali di controllo dei tre solenoidi + il reset del LCD (vedi schema)
3. SCL_CTRL: 8 bit, output only; registro dati @ 0x0021. Collezione di vari output, controlla lo schema per più dettagli. (Nello schema, i pin di questa porta sono indicati come SCL-nn, dove nn è il numero del pin nel package del SCL; SCL-43 corrisponde al bit 0, e gli altri seguono in ordine crescente)
4. SCL_BANK: 1 bit, output only; Pilota A14 sulla ROM: permette quindi di scegliere fra i due banchi di codice.

Tutta la logica di decodifica degli indirizzi di memoria per le porte, la RAM e la ROM, è contenuta nell’SCL, che procede a selezionare automaticamente i circuiti corrispondenti.

Comunicazione dati

Il Rotor comunica con il “traslatore di centrale” (di seguito indicato semplicemente come TRS) utilizzando la linea as/bs, dalla quale viene anche prelevata la corrente necessaria per l’alimentazione del circuito caricabatterie.

Le comunicazioni in direzione TRS→Rotor avvengono invertendo la polarità della linea di segnalazione (polarità normale: filo a NEGATIVO, filo b POSITIVO; N.B: i sistemi telefonici sono a TERRA POSITIVA, quindi è il filo B ad essere a terra) in modo temporizzato; queste inversioni vengono rilevate dal telefono mediante il fotoaccoppiatore OP3.

Le comunicazioni in direzione Rotor→TRS avvengono invece variando la corrente assorbita dal telefono sulla linea di segnalazione: quando il telefono desidera trasmettere, il fotoaccoppiatore OP4 viene attivato, cortocircuitando i tre transistor T5,T6,T7 e aumentando la corrente di linea; il TRS rileva questa variazione mediante un proprio fotoaccoppiatore inserito in serie alla linea.

Nota: questo tipo di comunicazione è stato “ereditato” dal precedente telefono modello G+M, tant’è che nel brevetto di uno dei TRS compatibili con il Rotor il circuito di interfaccia è indicato con il nome di SGM (“Sonda Gettone+Moneta”)

Esistono due diversi “protocolli” di comunicazione, utilizzati in situazioni differenti:

1) Protocollo “Telegrafico”:


Si tratta del più semplice dei due, ed è simile alla selezione decadica; una comunicazione di questo tipo si può analizzare dividendola in 5 fasi, come visibile nell’immagine.

N.B: I segnali sono mostrati nella forma in cui appaiono sulle porte di I/O del microcontrollore. I segnali in entrambe le direzioni (Rotor→TRS e TRS→Rotor) assumono in questo caso lo stesso aspetto in termini di forme d’onda.
Per i segnali provenienti dal TRS, il livello logico ALTO corrisponde a polarità normale, mentre quello basso a polarità invertita; per i segnali provenienti dal Rotor, il livello ALTO corrisponde a OP4 off e quindi corrente di linea minima (la sola corrente di alimentazione), mentre quello basso corrisponde a OP4 on e corrente massima
A) IDLE: linea “a riposo”
B) START: impulso di inizio comunicazione. Per le trasmissioni provenienti dal Rotor, ha due possibili durate; Per le comunicazioni in direzione TRS→Rotor, diversi valori per lo start sono ammessi, vedi più sotto per i dettagli
C) SPACE, MARK: In seguito all’impulso di start, i dati da trasmettere sono inviati cifra (decimale) per cifra sotto forma di una serie di impulsi negativi (mark), lunghi 10ms, separati da pause della stessa lunghezza (space). La cifra trasmessa è pari al numero di mark + 1; lo 0 è trasmesso sotto forma di 10 impulsi.
D) STOP: impulso di fine trasmissione. Ha sempre durata 50ms in direzione Rotor→TRS, mentre in direzione opposta sono ammesse due differenti lunghezze che, di nuovo, cambiano il modo in cui vengono interpretati i dati trasmessi; vedi sotto per i dettagli

Tipi di trasmissioni telegrafiche

DIREZIONE TRS → Rotor

1) Comando: start 50ms, stop 50ms Il telefono interpreta il numero inviato come indice del comando da eseguire. Sono supportati 7 comandi, descritti più avanti in questo documento. Se il numero di impulsi risulta > 7, la trasmissione viene semplicemente ignorata
2) Addebito monete: start 35ms, stop 50ms Comando di “addebito” per il credito relativo alle monete (il credito “monete” ed il credito “carte” sono gestiti in modo completamente separato all’interno del software del telefono) Il telefono sottrae una somma pari a cifra_inviata*100L al credito e visualizza il nuovo credito
NOTA: Per le transazioni a monete, è sempre necessaria una successiva conferma di incasso, altrimenti il telefono restituisce la moneta.

NOTA 2: Prima di inviare un comando di addebito, è necessario inviare almeno una richiesta credito al telefono, vedi l’elenco comandi più in basso, altrimenti l’incasso non andrà a buon fine
3) Addebito schede: start 20ms, stop 50ms Comando di “addebito” per le schede telefoniche. Il telefono sottrae una somma pari a cifra_inviata*100L al credito, visualizza il nuovo credito e aggiorna il credito sulla banda magnetica della scheda.
NOTA: In questo caso non è necessaria una conferma di incasso, il lettore integrato cancella il credito non appena il comando è ricevuto.
NOTA 2: Se il telefono riceve questo comando quando non è presente una scheda e/o non è presente nessun lettore, la cifra ricevuta viene visualizzata sul LCD, fino ad un massimo di 4 cifre contemporaneamente (10 impulsi = “0”; i valori da 11 a 15 corrispondono a simboli)
4) Telereset Rotor: start 700ms, stop 50ms Permette al TRS di reinizializzare il Rotor; Il telefono si pone in FS e attende una nuova configurazione.
NOTA: non si tratta di un vero e proprio reset, in quanto il software si limita a cancellare la configurazione in memoria
5) Possibile telereset LIOD: 70ms < start < 700ms Alla ricezione di questa trasmissione, il telefono resetta una serie di variabili relative allo stato del LIOD; ulteriori indagini sono necessarie
6) Incasso monete: start 50ms, stop 90ms Comando di incasso/conferma addebito per le monete: conferma la riduzione del credito effettuata dai comandi di addebito. La cifra inviata può avere valore 1-3, altrimenti il comando viene ignorato. Dalle prove effettuate sembra che solo il valore 2 venga accettato. NOTA: Come specificato per il comando di addebito, l’incasso può avvenire solo se il credito (inteso come il numero ed il tipo di monete inserite) è stato inviato dal telefono al TRS

DIREZIONE ROTOR → TRS

1) Comunicazione generica: start 40ms, stop 50ms Utilizzata dal telefono quando deve inviare informazioni al TRS, sia che si tratti di risposte a comandi (eccetto comando “richiesta credito”) sia che si tratti di allarmi (trasmissioni “spontanee”). In questo caso il telefono invia una singola cifra.
2) Conferma incasso: start ??, stop 50ms Come sopra, ma utilizzata per confermare la ricezione con successo del comando di incasso. La cifra inviata dal telefono corrisponde a quella che era stata inviata dal TRS all’interno del comando di incasso. In caso di incasso non riuscito, non si riceve nessuna risposta dal telefono.
NOTA: A differenza dei telefoni precedenti, nel Rotor 2 la conferma di incasso NON avviene necessariamente quando la moneta transita davanti al sensore posto alla fine del canale di incasso; è sufficiente che il telefono abbia registrato la richiesta per ottenere la conferma incasso.
3) Credito: start 40ms ripetuti (vedi foto), stop 50ms Tipo di trasmissione utilizzato per comunicare al TRS il credito IN MONETE inserito nel telefono; si tratta di tre cifre inviate una di seguito all’altra, separate da uno “start” da 40ms inviato dopo gli impulsi della 1a

e 2a
cifra.
La 1a

cifra ha valore 200L, la 2a

ha valore 100L, la 3a
è sempre 0.
NOTA: Il telefono non invia mai più di 14 impulsi per la 1a

cifra e 6 per la 2a.. In caso di credito superiore a 3400L, quindi, il valore ricevuto può non rispecchiare il credito effettivamente presente nel tamburo.
NOTA 2: Il telefono risponde al comando di richiesta credito solamente la 1a
volta che lo
riceve all’interno di una conversazione. Per le monete inserite successivamente, il telefono invia in modo spontaneo altre 3 cifre che indicano il credito aggiunto (quindi non il totale, ma solo quello relativo alle monete appena inserite).
4) Segnalazioni “spontanee”/allarmi: start 40ms, stop 50ms

Il formato è esattamente lo stesso delle comunicazioni generiche, ma in questo caso si tratta di dati inviati dal telefono senza che il TRS invii alcuna richiesta. Si tratta anche qui di una “cifra” sola, e i valori noti sono:
- 10 → Cornetta riappesa
- 11 → Interruzione colloquio con lettore interno (guasto MIA, rimozione lettore ecc)
- 12 → Sconosciuto
- 13 → Cassaforte aperta (solo Corazzato)
- 14 → Cassetta monete rimossa (solo Corazzato)
- 15 → Perdita linea voce
2) Protocollo “pseudo-BPSK”


Si tratta del secondo protocollo supportato, utilizzato principalmente per inviare i dati di carte di credito (telefoniche e/o “commerciali” di tipo Diners e AMEX) e schede telefoniche prepagate.
In questo caso la trasmissione è di tipo binario e, da quanto determinato finora, sembra sia utilizzata solo in direzione Rotor → TRS
La trasmissione con questo protocollo inizia sempre con uno start, composto da un picco negativo lungo 20ms seguito da 10ms di pausa (nella foto, è la parte fra il cursore T ed il cursore 0), seguito poi dai dati binari.
Tali dati sono codificati con quella che possiamo definire codifica pseudo-BPSK (Binary Phase Shift Keying):
- Un bit a 0 è codificato come 10ms a livello alto seguiti da 10ms a livello basso

- Un bit a 1 è codificato come 10ms a livello basso seguiti da 10ms a livello alto

Nella foto di esempio, i primi 4 bit trasmessi sono 0111 (→ 0x7)

Comunicazione lettore-Rotor:

Come molti aspetti di questo telefono, la comunicazione fra lettore di schede interno (d’ora in poi indicato come LIOD, “Lettore Integrato a Obliterazione Durante”, come viene chiamato nei manuali) avviene in modo assolutamente non standard.
A livello elettrico, la comunicazione avviene tramite due linee unidirezionali; d’ora in poi indicheremo come TXD la linea che sposta dati in direzione Rotor→LIOD e RXD quella in direzione opposta
(N.B: nello schema le linee sono indicate dal punto di vista del LIOD, quindi invertite rispetto a questo documento).
Un’ulteriore linea viene utilizzata dal telefono per rilevare la presenza del lettore; un resistore di pull’up all’interno del lettore fa sì che questa linea sia a +5V con lettore presente, 0 altrimenti.

Nota: La scheda di interfaccia lettore (indicata d’ora in poi come MIA, “Modulo Interfaccia Aggiuntivi”, di nuovo per coerenza con il manuale) è decisamente più complicata di quanto necessario in quanto è concepita per supportare due differenti tipi di lettore.
Non sappiamo di per certo quale sia il secondo lettore teoricamente supportato (la documentazione lo indica semplicemente come lettore di debito, ma il manuale, almeno la versione più recente, indica che l’unico lettore effettivamente utilizzato è il LIOD); un’ipotesi è che si tratti del mitico “lettore azzurro”, un lettore di schede telefoniche progettato per l’uso con il G+M e prodotto in numeri molto ridotti, ma non dispongo di un lettore per confermare questa ipotesi e non sappiamo nemmeno se il codice lato Rotor sia completo e funzionante.
Un ulteriore pin del microcontrollore viene utilizzato per scegliere fra i due e l’interfaccia per l’altro lettore utilizza dei pin in più, ma per semplicità ignoreremo completamente questa prossibilità.
Tutte le foto e le descrizioni da qui in poi fanno riferimento ai segnali come visti dal microcontrollore del Rotor. In ogni caso, una volta che il telefono è inizializzato ed ha rilevato correttamente il lettore, il MIA passa il segnale RXD (e DET) inalterato dal lettore al telefono, mentre TXD viene invertito.
Il successivo Rotor O.V. fa a meno del MIA e controlla il lettore direttamente dal micro.

Nota 2: Esistono diverse revisioni del LIOD, l’ultima delle quali viene indicata nel manuale come LI O.D./R.I (“Lettore Integrato a Obliterazione Durante e Restituzione dalla bocchetta di Ingresso). Il manuale fornisce ulteriori dettagli a tale proposito; l’interfaccia rimane la medesima.

Il protocollo di comunicazione non è né RS232 standard, né tanto meno una delle interfacce sincrone “comuni” quali SPI, I2C ecc.
Il Rotor agisce sempre come master della comunicazione, in quanto il lettore non può iniziare una comunicazione ma solo inviare dati quando clockato dal telefono.
Vediamo un esempio di una comunicazione:


In bianco RXD, in arancio TXD; TXD, come intuibile dall’immagine, ha la doppia funzione di trasportare comandi in direzione Rotor→LIOD e di clockare il lettore per la risposta.
La comunicazione si articola in due fasi:
1. Comando: (sempre proveniente dal telefono e destinato al lettore) si tratta del primo impulso positivo; I differenti comandi sono codificati variando la lunghezza di tale impulso. Il firmware del Rotor 2 versione 1.4, l’ultima rilasciata, supporta 10 comandi; il lettore è in grado tuttavia di riconoscerne un numero più ampio (potrebbero essere comandi di test/comandi avanzati supportati solo dal Rotor OV). Il lettore risponde semplicemente pilotando RXD allo stesso livello di TXD (salvo casi particolari indicati più avanti)
2. Clock + risposta: Il telefono a questo punto procede a clockare il lettore in modo da leggere la risposta inviata da quest’ultimo. Ciascuno dei quattro impulsi di clock inviati dal telefono ha entrambi i fronti attivi: RXD viene campionato quindi due volte per impulso, una sul fronte di salita ed una sul fronte di discesa, con un piccolo delay fra il fronte di clock ed il campionamento per consentire al lettore di pilotare RXD al valore appropriato. Gli impulsi di clock sono lunghi circa 250 us, separati fra loro e dal comando da una pausa di 2,5 ms.

Nella trasmissione di esempio, il telefono invia il comando “di idle” (comando che viene inviato continuamente dal telefono per segnalare al lettore che è tutto ok e può accettare schede), mentre il lettore risponde con 0x07.

Esiste una modalità di trasmissione particolare, che chiameremo burst mode, utilizzata per la lettura delle schede e per alcuni comandi particolari. In questa modalità, dopo aver letto il primo byte di risposta al comando, il Rotor non riporta la linea a riposo ma, ad una distanza circa 5 ms (il timing non è critico: pause molto più lunghe sono accettabili), ripete altri 4 clock per un totale di 40 impulsi, leggendo cioè 10 byte oltre quello iniziale.
La durata del burst è fissa a 10 byte.

Esiste, come accennato sopra, un caso particolare: nel caso in cui il lettore sia occupato a leggere una scheda, si comporta come visibile al centro della foto seguente:

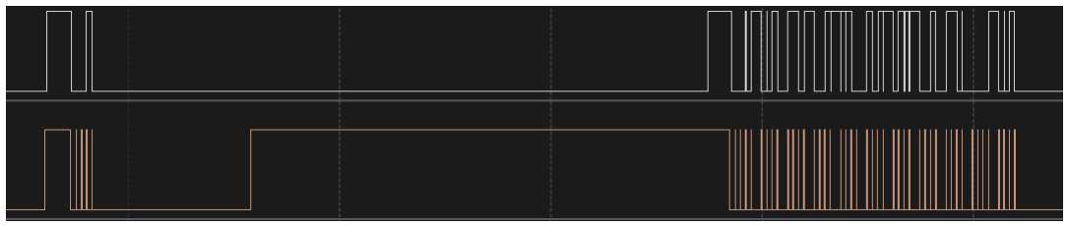
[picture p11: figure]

Il lettore, cioè, rilevato l’inizio del comando, non risponde portando RXD a livello alto (quasi) istantaneamente, come di consueto, ma lo fa solo una volta terminata la lettura. In questo caso la durata del comando è misurata a partire dal rising edge di RXD
Una lettura avvenuta con successo porta ad una differente risposta al comando di IDLE (più dettagli sulle risposte in seguito), seguito dai dati delle schede trasmessi in burst mode.

Comandi e risposte lettore:

Le durate dei comandi, per il firmware lettore v3.1 04/05/93, sono:
- 0ms < len <= 2ms | CMD0: NOP
- 2ms < len <= 17ms | CMD1: Stato lettore/IDLE
- 17ms < len <= 32ms | CMD2: Possibile comando di addebito
- 32ms < len <= 47ms | CMD3: Sconosciuto
- 47ms < len <= 62ms | CMD4: Espulsione scheda
- 62ms < len <= 87ms | CMD5: Modalità Rotor (necessario per il normale funzionamento)
- 87ms < len <= 102ms | CMD6: Reinvia dati scheda*
- 102ms < len <= 117ms | CMD7: Richiesta dati extra CCC *(ulteriori 10 byte)
- 117ms < len <= 132ms | CMD8: Sconosciuto
- 132ms < len <= 147ms | CMD9: NOP
- 147ms < len <= 162ms | CMD10: Sconosciuto
- 162ms < len <= 177ms | CMD11: Sconosciuto
- 177ms < len <= 195ms | CMD12: Sconosciuto
- 195ms < len <= 207ms | CMD13: NOP
- 207ms < len <= 222ms | CMD14: Sconosciuto
- 222ms < len <= 237ms | CMD15: Sconosciuto, possibile reset errori meccanica.
- 237ms < len <= 252ms | CMD16: Richiesta versione firmware*
- len > 252ms | NESSUN COMANDO

I comandi seguiti da un asterisco richiedono l’uso del burst mode. I comandi indicati come NOP non hanno effetto.
Ulteriori dettagli in seguito:
- CMD4: Espulsione scheda. Espelle un’eventuale CTP trattenuta nell tamburo del lettore. Per le CC (commerciali o telefoniche) è necessario inviare un comando di espulsione prima di poter leggere un’altra scheda, nonostante le CC non siano fisicamente trattenute dal lettore.
- CMD5: Modalità “Rotor”. Non si sa quale sia la modalità di default, ma i dati delle schede appaiono corretti solo dopo aver eseguito questo comando.
- CMD6: Ripetizione dati scheda. Il telefono reinvia i primi 10 byte del buffer schede, oppure 10 byte nulli se non c’è nessuna scheda presente. Richiede burst mode.
- CMD7: Richiesta ulteriori dati CCC. Una carta di credito “commerciale” (Diners/AMEX nello specifico, ma il lettore accetta qualsiasi scheda ISO) contiene più di 10 byte di dati; questo comando permette di richiedere gli ulteriori 10 byte. Richiede burst mode, NON contiene checksum
- CMD16: Richiesta versione firmware lettore. Invia 10 byte in burst mode, codificati BCD; i primi 2 corrispondono alla revisione software (es: 0x03 0x01 → 3.1), i successivi tre la data di rilascio (0x04 0x05 0x93 → 4/5/1993). Termina con un checksum XOR dei 10 byte precedenti (risposta al comando + 10 byte di dati)

Analizziamo ora le risposte. È importante notare che per risposta si intende il byte inviato dal lettore appena ricevuto il comando; per i comandi che fanno uso di burst mode, quindi, i byte ricevuti sono 1+10, cioè 1 di risposta + 10 di dati.
Le risposte, almeno per questa versione del FW, sono univoche: quindi ciascuna risposta è specifica ad un determinato comando.
Risposte conosciute:
- 0x07 Lettore OK. Inviata dal comando di richiesta stato per confermare che il lettore è funzionante e pronto.
- 0x03 Seguono dati CTP. Indica la corretta lettura di una scheda telefonica prepagata; inviato in risposta a CMD1, attiva burst mode ed è seguito da 10 byte nel formato PP PP PP PP SS SS SS SS
CC CK, cioè 4 byte della 1a | trama + 4 byte della 2a trama + 1 byte credito (in unità) + 1 byte
checksum che è lo XOR dei 10 precedenti (quindi incluso lo 0x3). La 2a
| trama è pari a una serie di
0x00 se la scheda è scarica; ulteriori dettagli nel documento sulle schede
- 0x04 Seguono dati CTC. Indica la corretta lettura di una carta di credito telefonica; inviato in risposta a CMD1, è seguito da 9 byte di dati della banda magnetica + 1 byte di checksum, che è di nuovo lo XOR dei 10 precedenti.

- 0x11 Seguono dati CCC. Inviato come risposta a CMD1, indica la corretta lettura di una CCC (Carta di Credito Commerciale) inserita dall’utente. Attiva burst mode ed è seguita da 10 byte di dati letti dalla banda magnetica e nessun checksum. Per una CCC è necessario richiedere separatamente gli altri 10 byte di dati, vedi sopra.
- 0x0A Richiesta espulsione ricevuta. Indica la ricezione del CMD4. Per una CTP NON è sufficiente a garantire che la scheda sia stata meccanicamente espulsa dal tamburo.
- 0x0C Modalità Rotor attivata. Risposta al CMD5, conferma l’esecuzione del comando.
- 0x0E Seguono dati extra CCC. Inviata come risposta al CMD7, provoca l’attivazione del burst mode; è seguita da 10 byte di dati della scheda. Come specificato prima, per le CCC NON c’è checksum
- 0x13 Segue versione FW. Inviata come risposta al CMD16, attiva burst mode ed è seguita da 9 byte di versione + 1 di checksum, che è 0x13 XOR i 9 byte successivi
- 0x47 CTP espulsa. Conferma l’espulsione meccanica di una CTP; inviato in risposta a CMD1, può essere inviato anche senza che il telefono abbia richiesto l’espulsione della scheda, come nel caso di una scheda scarica o non valida.
- 0xEE Risposta a CMD15, conferma l’esecuzione del comando.

Sequenza di boot del telefono:

Il telefono, per funzionare correttamente, richiede due cose:
1. Batteria tampone principale (6V piombo) sufficientemente carica.
2. Configurazione esterna e contatori gestionali (contenuti nella RAM sulla board “RAM esterna”) validi
La batteria tampone della RAM esterna, che consente al telefono di mantenere configurazione esterna e contatori gestionali memorizzati anche con batteria tampone principale scarica, non è strettamente necessaria per il funzionamento del telefono.

Se la condizione numero 2 è verificata, il telefono può essere avviato in modalità normale (entrambi i dipswitch accanto al display su off) semplicemente premendo reset; terminato il boot, il telefono visualizza F.S. (con LED di “fuori servizio” spento) e si pone in attesa della configurazione remota dal TRS
Altrimenti, se i dati di configurazione non sono validi (ad es. telefono con batterie scariche appena rimesso in servizio), è necessario avviare il telefono con il microswitch di configurazione (il sx, vedi manuale) in posizione ON; questo riscriverà la configurazione in RAM.
Se, inoltre, i contatori gestionali (totale monete in cassaforte ecc) risultano non validi, è necessario avviare il telefono tenendo premuto (dal reset fino all’avvio completo) il pulsante del gestore, che è il pulsantino posto all’interno dello scomparto della cassaforte, visibile con cassetta rimossa.

Sequenza di configurazione remota:

Il telefono, dopo ogni boot avvenuto con successo, si pone in F.S. in attesa della configurazione remota; la procedura in questione è piuttosto semplice, ed è visibile nell’immagine seguente

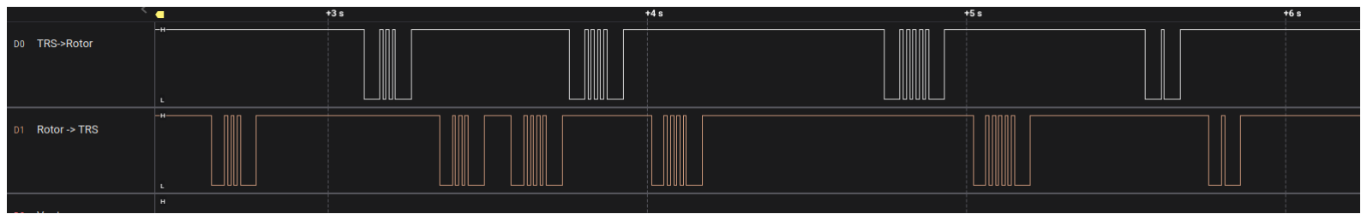
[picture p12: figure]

(riferita ad un telefono con LIOD installato e funzionante).
La procedura prevede la seguente sequenza (tutta eseguita usando il metodo di configurazione telegrafico):
1. Il telefono invia un 3 (prima cifra dello “stato lettore” visualizzato sul display all’avvio, cioè “30”, “33” o “34”, vedi manuale)
2. Il TRS risponde con un 3

3. Il telefono ripete il 3 precedente, quindi invia subito la seconda cifra dello stato lettore (in questo caso 4, lettore OK); Se il lettore è assente (“30” visualizzato sul display all’avvio), questo passaggio ed i due successivi vengono ignorati
4. Il TRS risponde ripetendo l’ultima cifra ricevuta e solo l’ultima (qui un 4)
5. Il telefono ripete la cifra appena ricevuta dal TRS (di nuovo 4)
6. Il TRS ora invia 5 (valore fisso hardcoded)
7. Il telefono risponde 5
8. Il TRS invia 1 (di nuovo un valore fisso)
9. Il telefono risponde 1
10. Il TRS invia quindi, una per una, le tre cifre corrispondenti al valore in lire del gettone telefonico (lo 0 è inviato con 10 impulsi); dopo ogni cifra il telefono risponde reinviando la cifra appena ricevuta al TRS.
11. La procedura di configurazione è ora conclusa ed il telefono è ora funzionante

Nota 1 sul punto 10: la prima cifra del costo del gettone non può essere 0
Nota 2 sul punto 10: a causa di un bug del codice, anche se il telefono può teoricamente accettare qualsiasi valore per le ultime due cifre del costo gettone (es: 123 lire, 488 lire ecc), solo valori multipli di 100 sono effettivamente validi (nello specifico, le ultime due cifre sono salvate in memoria, ma in diversi punti il codice è scritto partendo dal presupposto che il costo sia multiplo di 100 lire e quindi tali cifre sono ignorate)

Una volta terminata la configurazione iniziale, il telefono risulta funzionante e non necessita di ulteriori comunicazioni col TRS per essere utilizzato come un normale telefono. Si comporta sostanzialmente come un Rotor 1: non incassa monete, ma permette di effettuare e ricevere telefonate. Per le altre funzioni (incasso monete, telefonate con schede ecc) è necessario inviare uno o più dei comandi elencati di seguito:

Comandi TRS:

Informazioni note al momento:
- 1 → Lampeggio display. Possibilmente usato come “avviso ottico fine incasso” come per manuale.
- 2 → Conferma validità scheda telefonica; inviato dal TRS dopo aver ricevuto seriale+credito della scheda telefonica per confermare la sua validità e la correttezza del credito contenuto sulla manda magnetica. Nessuna risposta dal telefono.
- 3 → Azzeramento credito schede. Azzera il credito memorizzato dal telefono per quanto riguarda le schede (il credito per le schede e per le monete sono memorizzati separatamente). Se è presente una scheda nel lettore, questa viene espulsa senza alterare la banda magnetica Nessuna risposta dal telefono
- 4 → Azzeramento addebiti schede. Azzera eventuali addebiti per le schede che sono stati ricevuti dal telefono ma non processati.
- 5 → Richiesta credito monete. Il telefono invia il credito presente (vedi sopra per il formato)
- 6 → NOP. Al momento non si conoscono ulteriori effetti.
- 7 → Richiesta errori. Il telefono può rispondere con:
1 → Tutto ok.
3 → Guasto sezione monete
4, 5, 9 → Sconosciuti. Probabilmente errori relativi al LIOD.

NOTA: Per ragioni ignote, i codici di errore riportati sopra (incluso quello relativo alla sezione monete) vengono trasmessi SOLO se il lettore è presente. Un telefono privo di lettore risponde sempre “1” anche con sezione monetaria guasta.

La ricezione di un qualsiasi comando provoca un interrupt, eventualmente “svegliando” il micro dallo stato di standby. In presenza di un FS (non irreversibile) attivo, il telefono effettua un autotest.
Se il Rotor riceve un comando in chiamata, quando la cornetta viene riappesa il telefono trasmette 10 (vedi sezione “allarmi” più sopra per ulteriori segnalazioni spontanee)

Note varie:

Importante: se il lettore legge ed accetta una scheda prepagata (quindi una scheda leggibile e con credito != 0), questa viene trattenuta dal telefono in attesa di risposta dal TRS. Per riottenere indietro la scheda NON resettare il telefono: questo ne causa la cancellazione!! (come misura di sicurezza contro truffe con le schede). Il metodo corretto è di inviare un 3 da un TRS simulato, oppure disconnettere la linea telefonica di segnalazione, ed aspettare poi che il telefono invii al LIOD il comando di espulsione scheda.

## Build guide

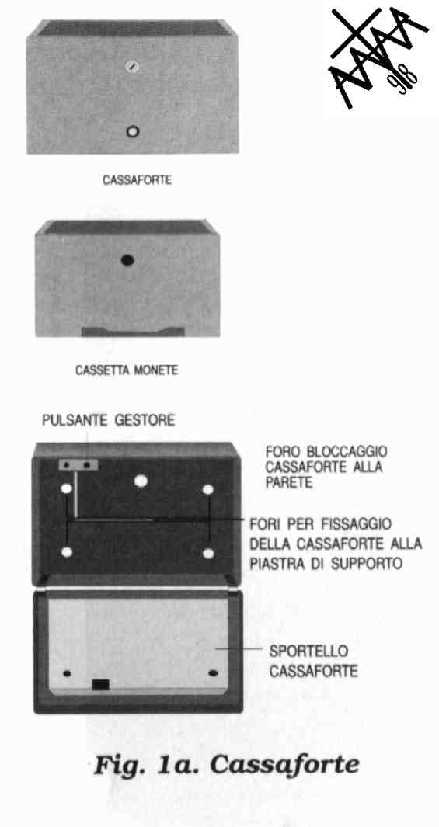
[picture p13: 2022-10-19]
manual/Rotor02.jpg

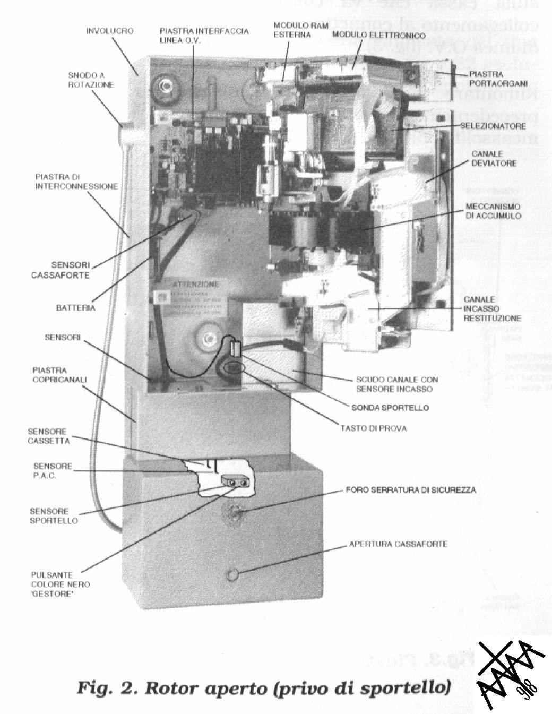
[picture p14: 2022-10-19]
manual/Rotor03.jpg

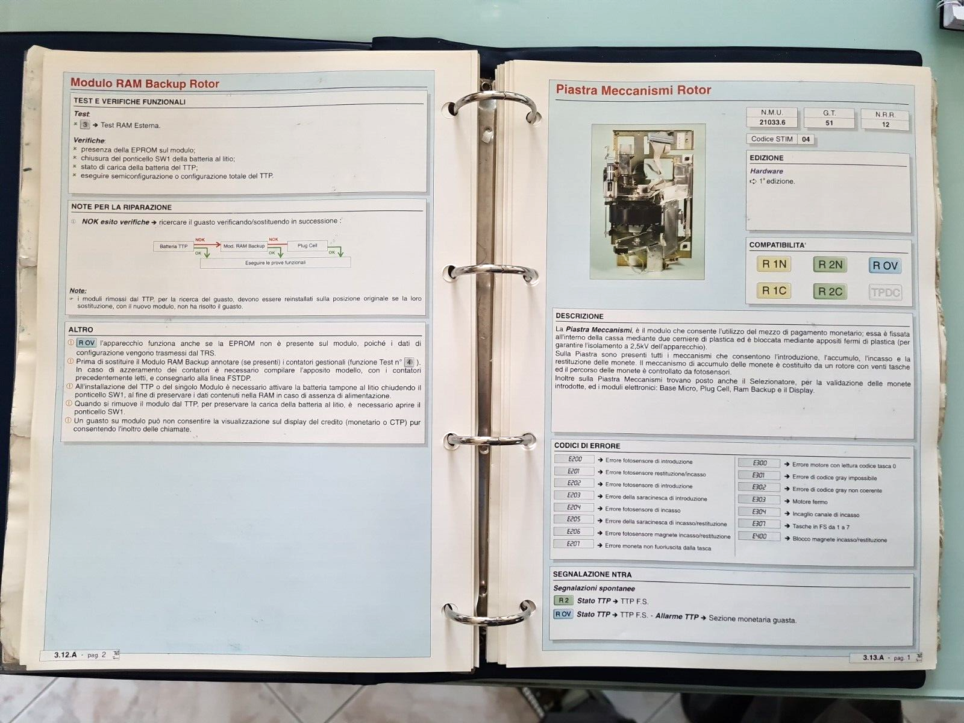
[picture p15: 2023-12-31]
manual/s-l1600 (7).png

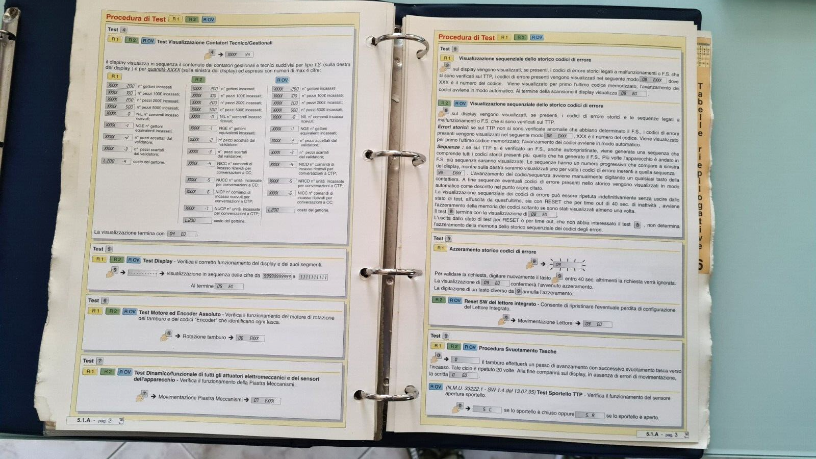
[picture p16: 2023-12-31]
manual/s-l1600 (4).png

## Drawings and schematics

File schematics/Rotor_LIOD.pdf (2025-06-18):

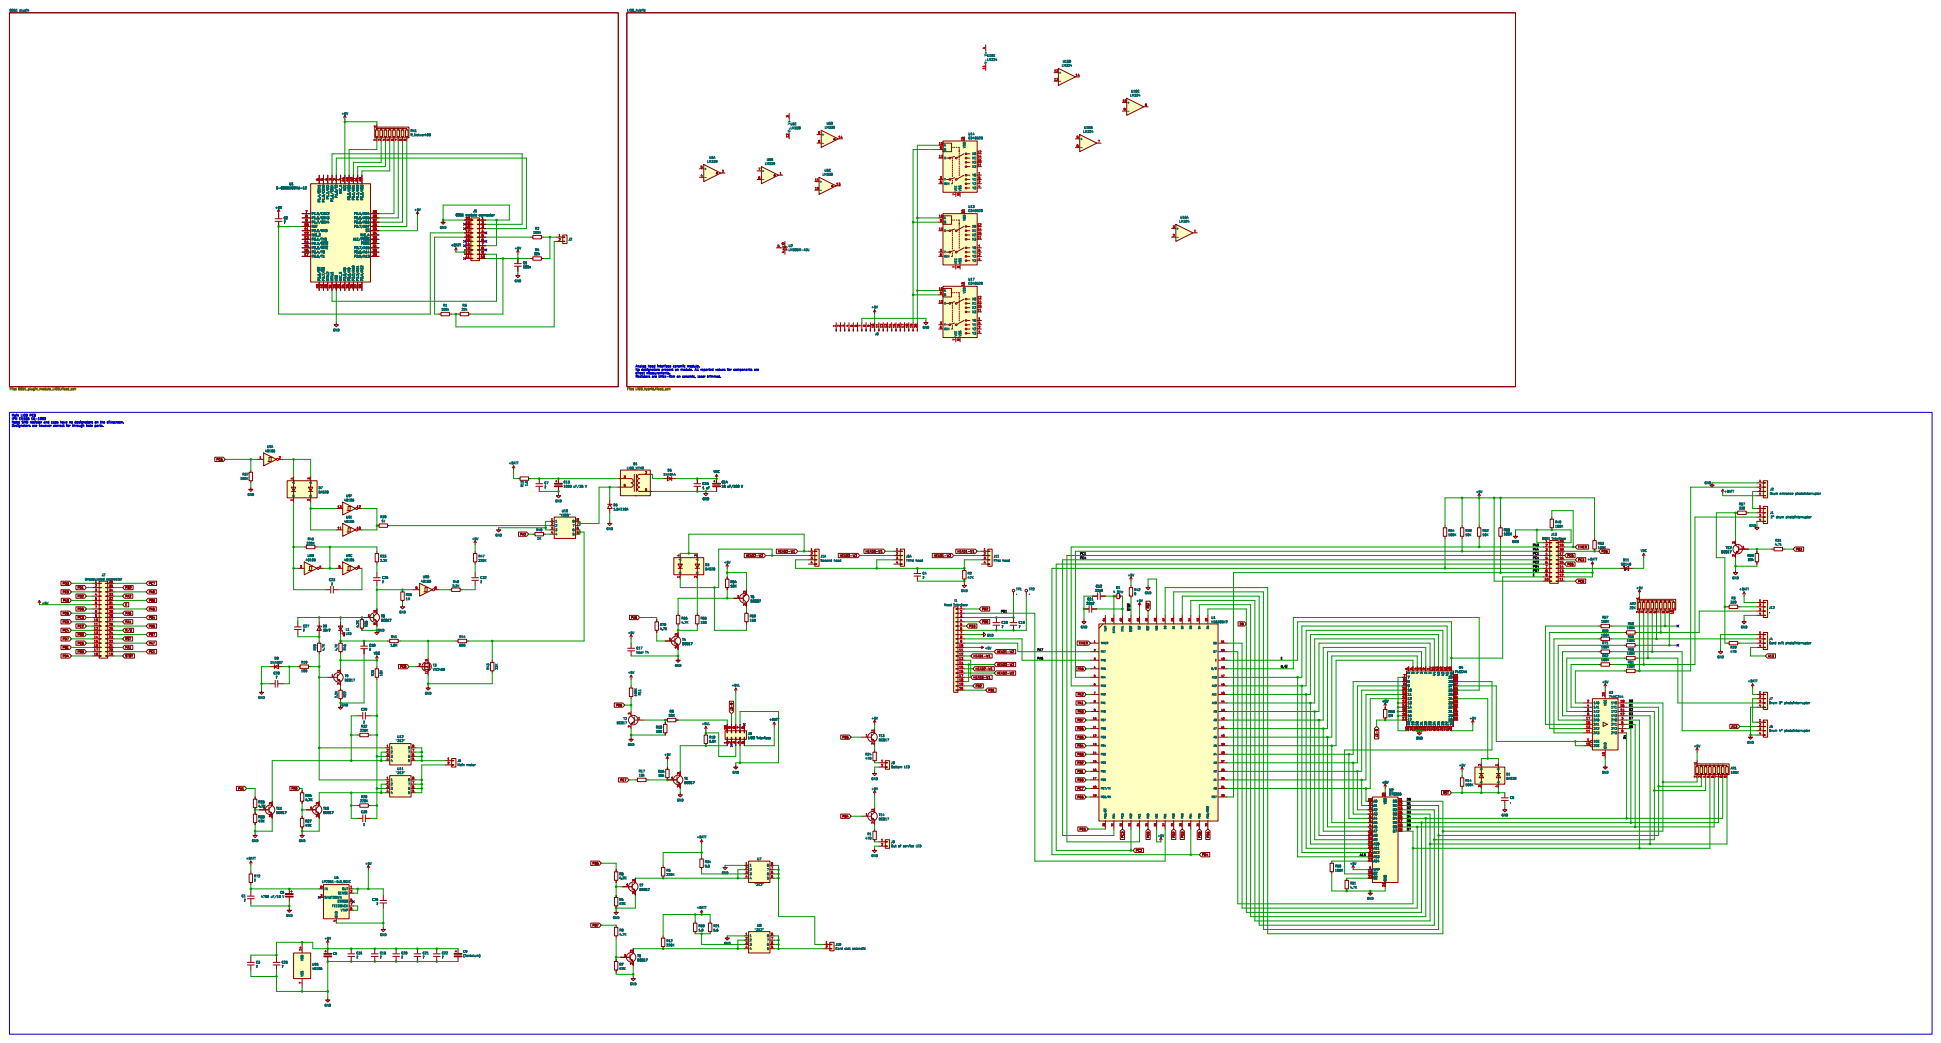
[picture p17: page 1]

8051 module connector +BATT GND

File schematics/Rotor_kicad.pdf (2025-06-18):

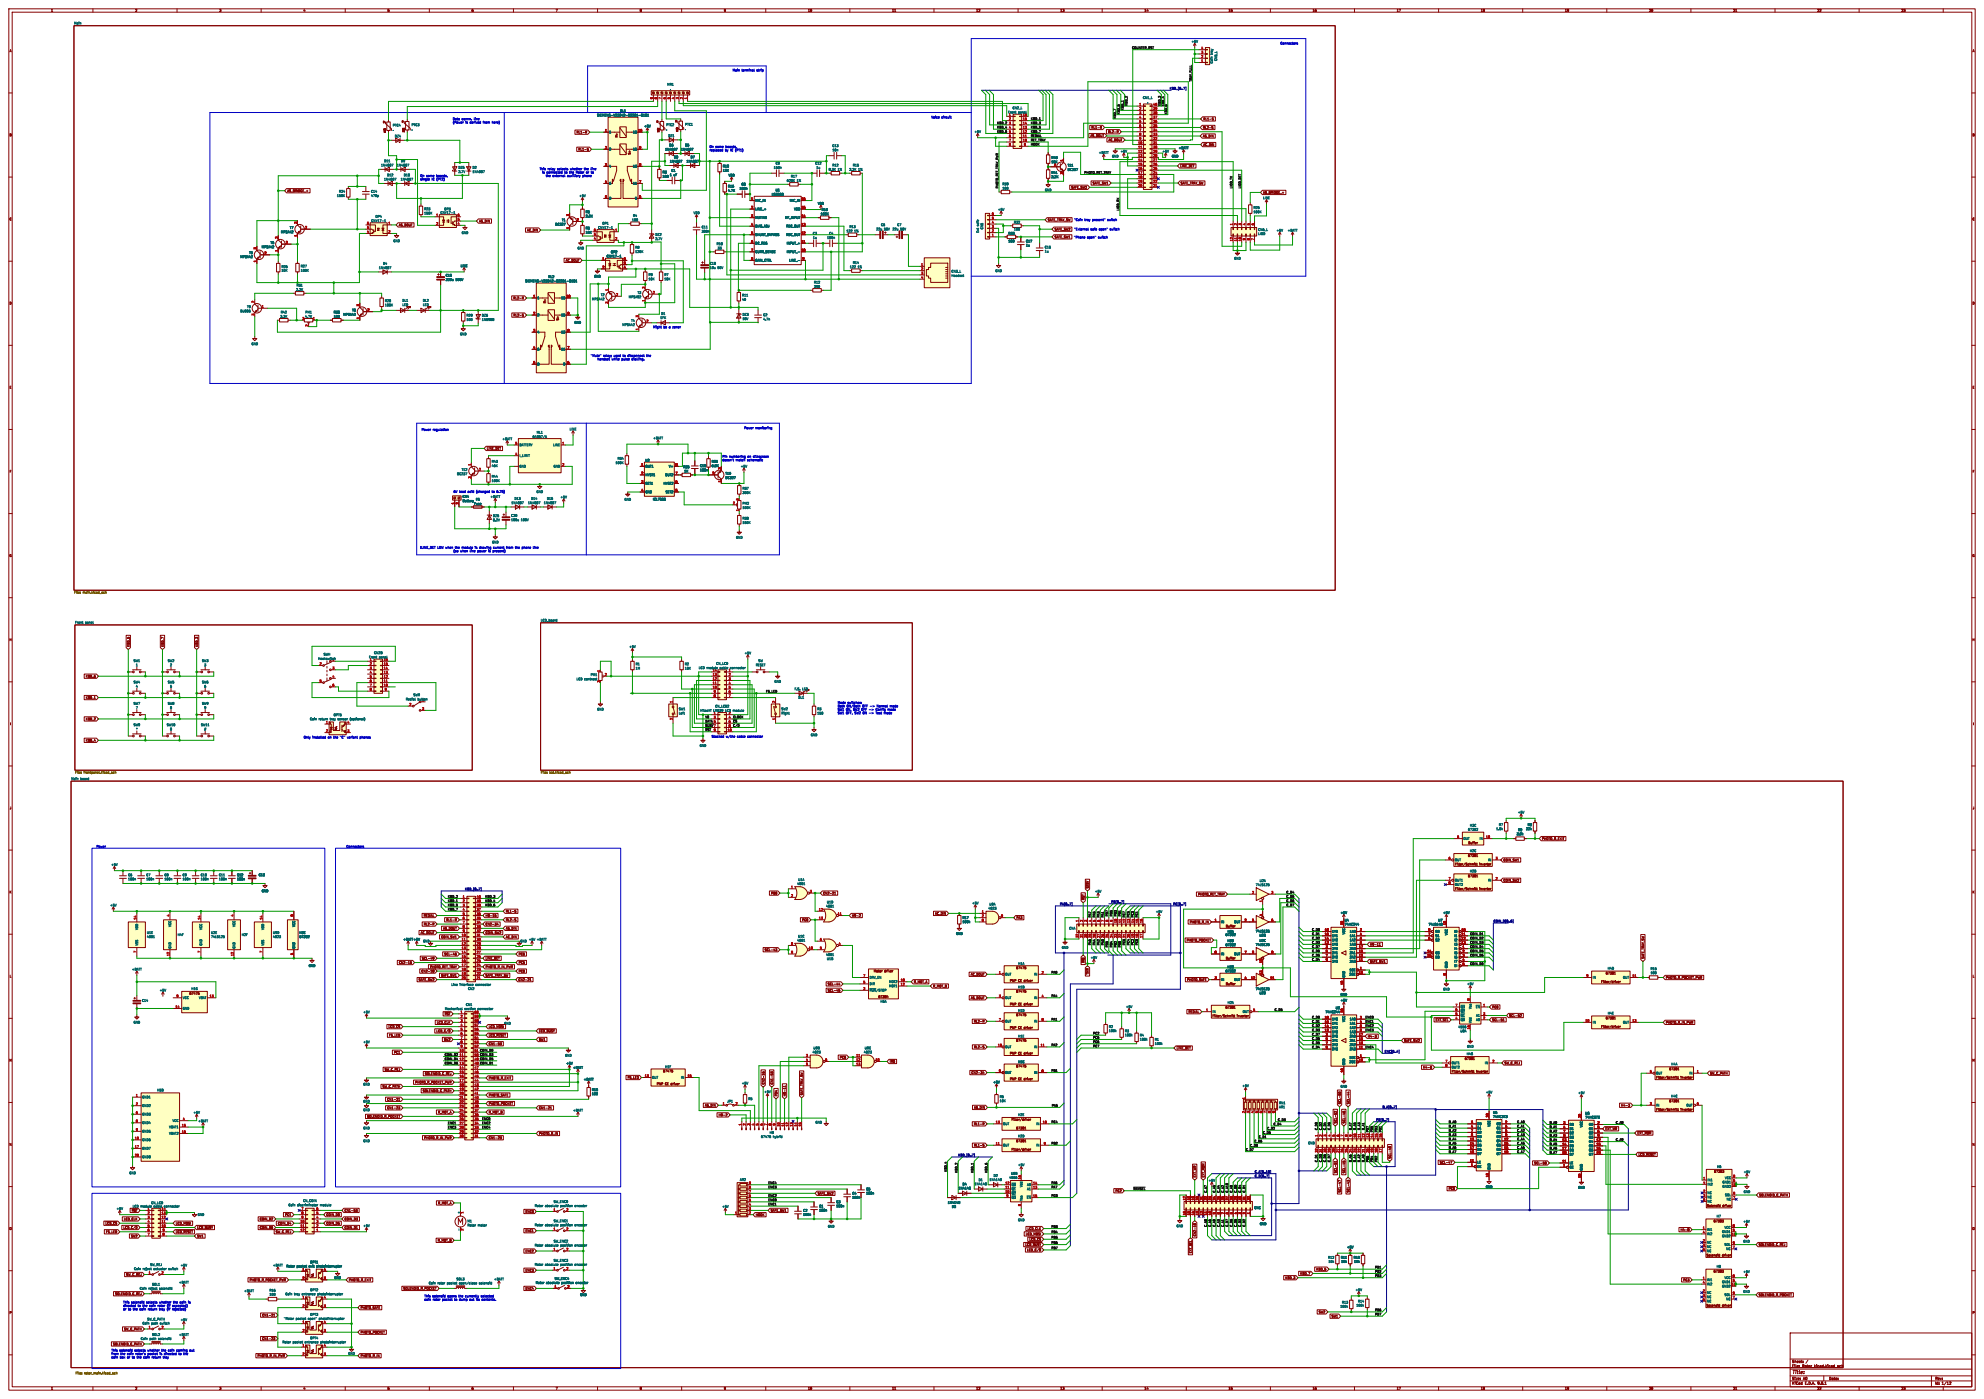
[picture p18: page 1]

Data comm. line
(Power is derived from here)

This relay selects whether the line

handset while pulse dialling.

doesn't match schematic Power monitoring

!LINE_DET LOW when the module is drawing current from the phone line

(so when line power is present)

File: main.kicad_sch
Front panel File: frontpanel.kicad_sch

LCD module cable connector 1

67384 Motor driver ~{RUN}/STOP

+BATT GND GND GND

-2 M1 Rotor motor 1 2 SW_ENC4 Rotor absolute position encoder 1 2 SW_ENC3 Rotor absolute position encoder C3

3 OPT1 Rotor pocket exit photointerrupter 1
SW_C_REJ

GND OPT1 Rotor pocket exit photointerrupter 1

coin rotor pocket to dump out its contents.

"Rotor pocket open" photointerrupter A

SOLENOID_C_PATH
coin box or to the coin return tray

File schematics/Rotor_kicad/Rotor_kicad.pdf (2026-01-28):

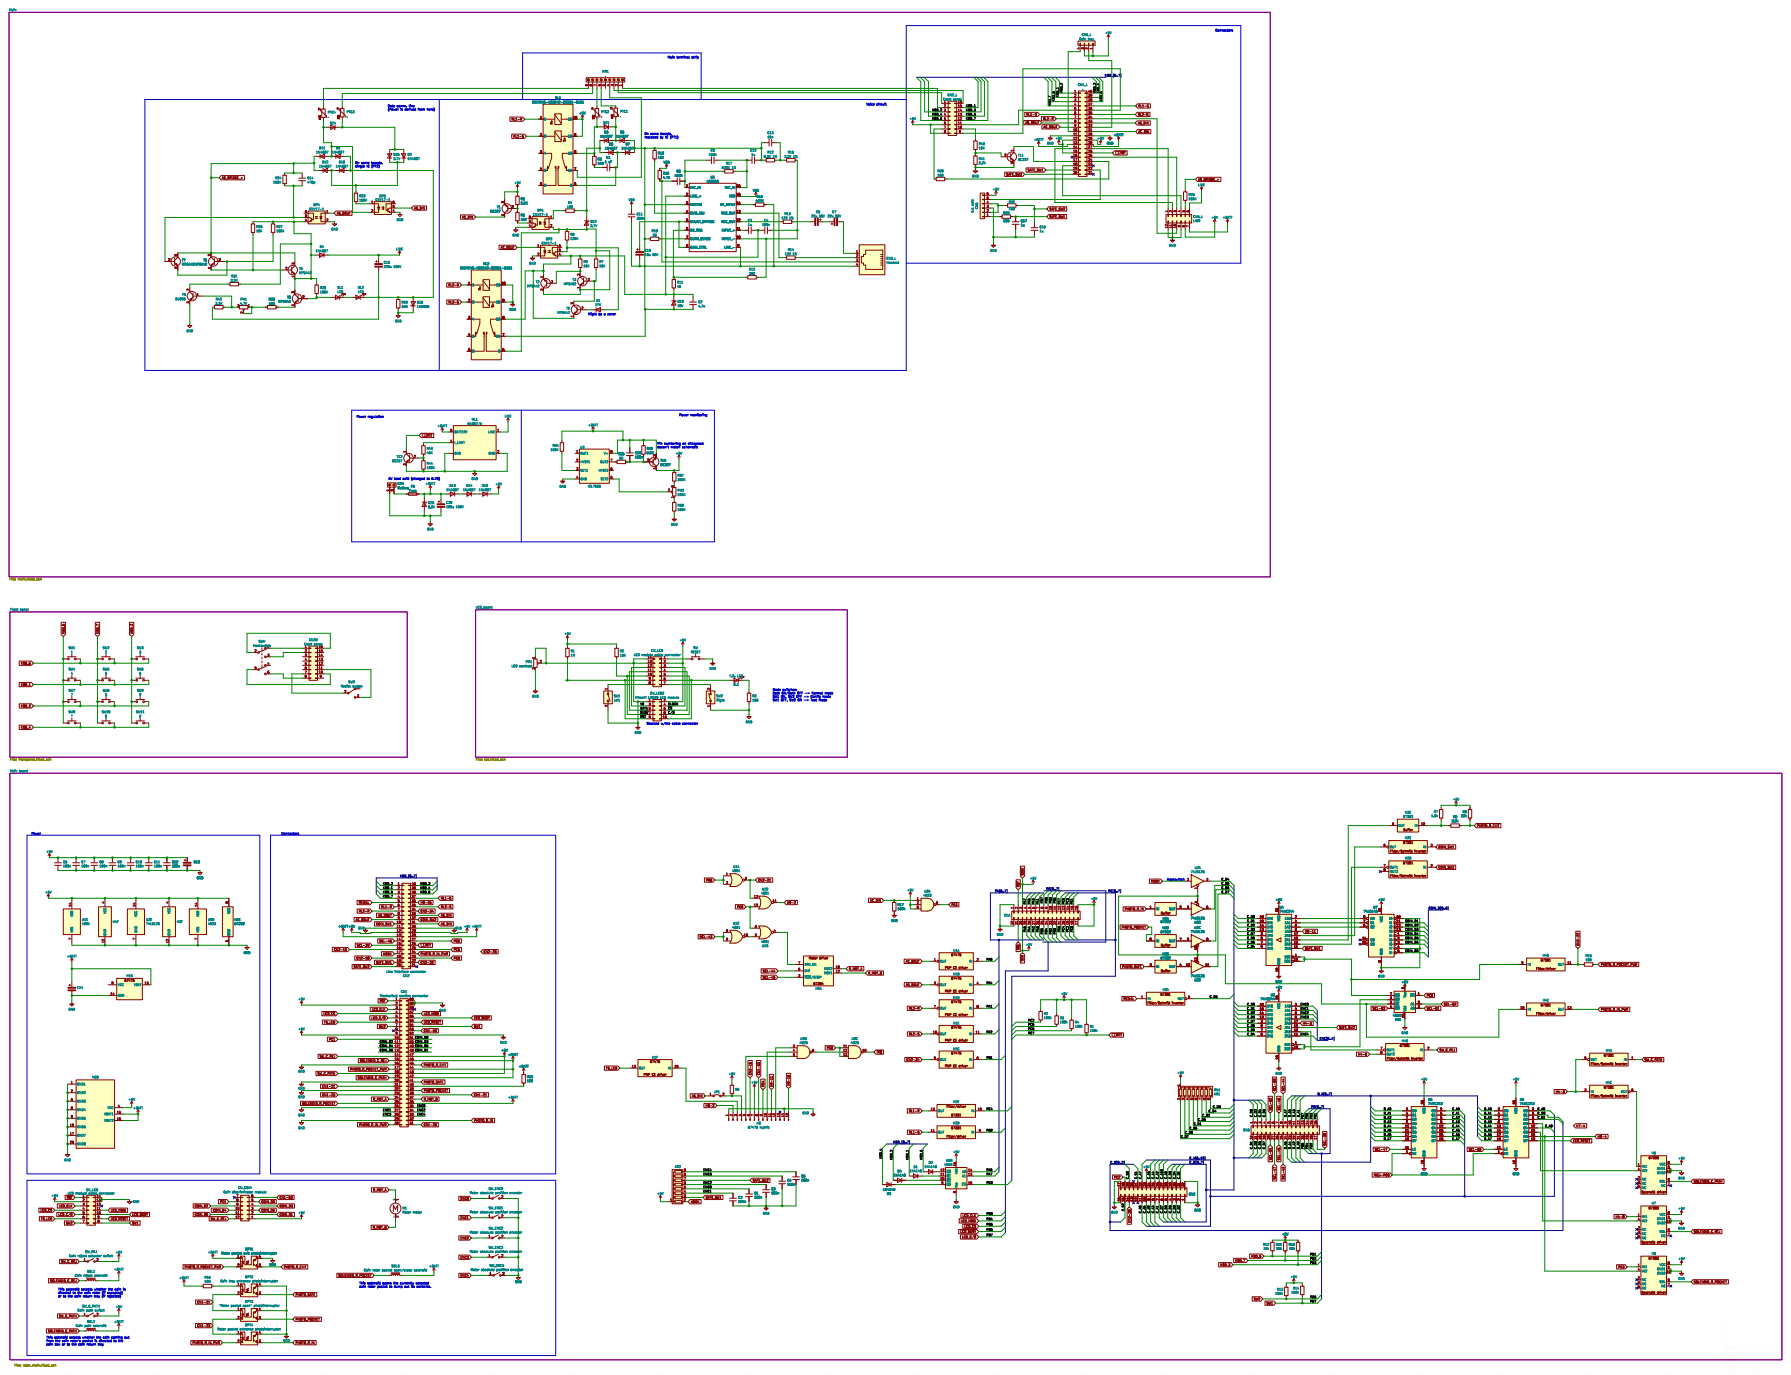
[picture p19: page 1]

File: main.kicad_sch
Front panel File: frontpanel.kicad_sch

LCD module cable connector

67475 PNP CE driver OUT

GND GND

~{RST}

"Rotor pocket open" photointerrupter GND

coin rotor pocket to dump out its contents.

coin box or to the coin return tray

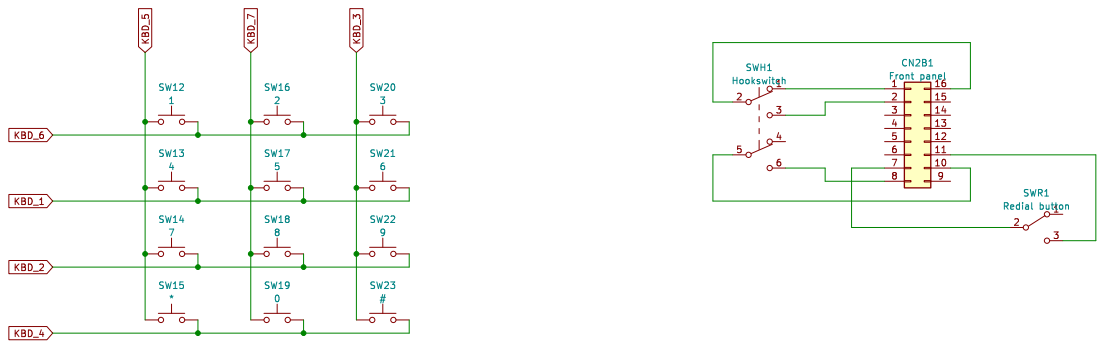
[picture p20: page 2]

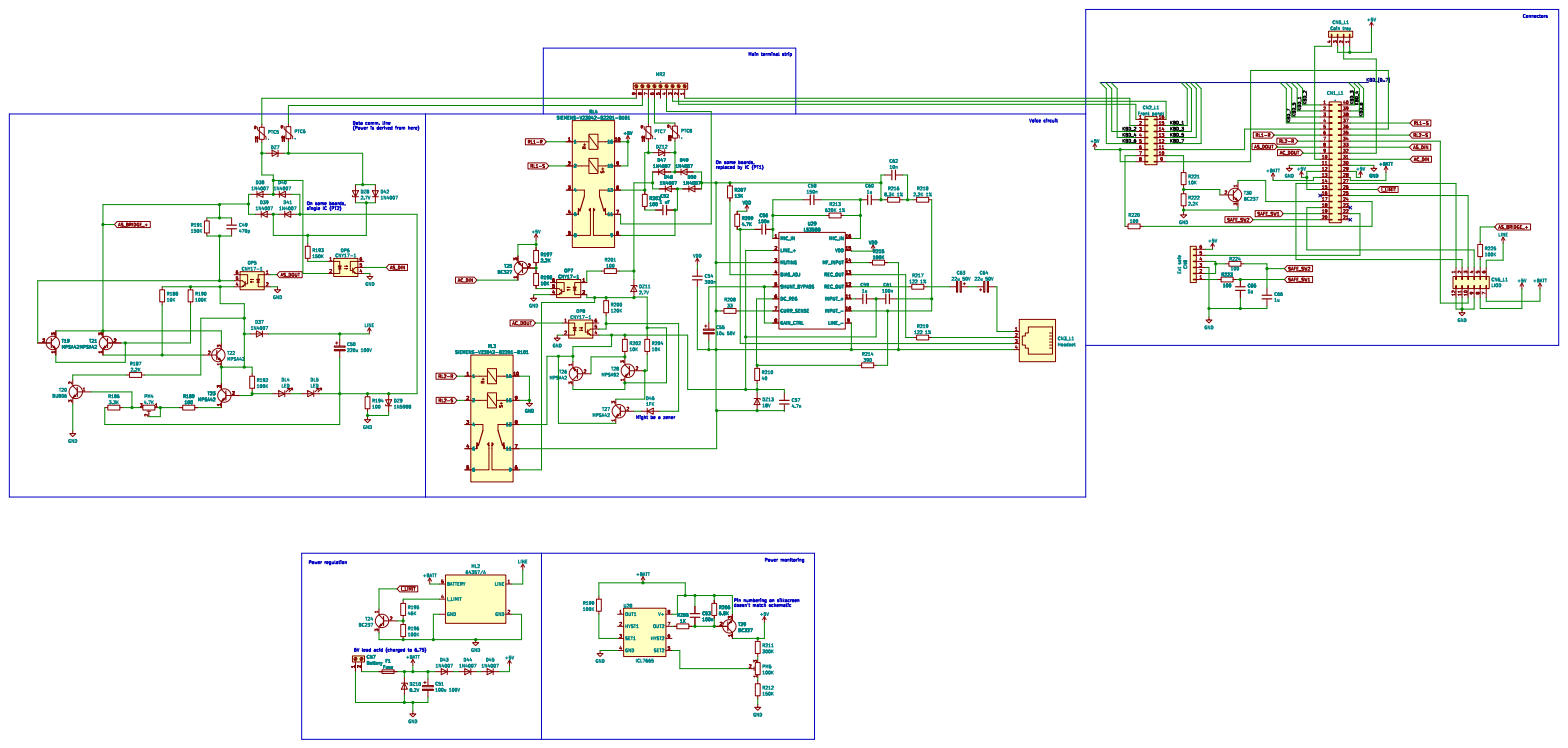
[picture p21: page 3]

Data comm. line
(Power is derived from here)

Power monitoring Power regulation

Id: 3/12 Title: File: main.kicad_sch Sheet: /Main/

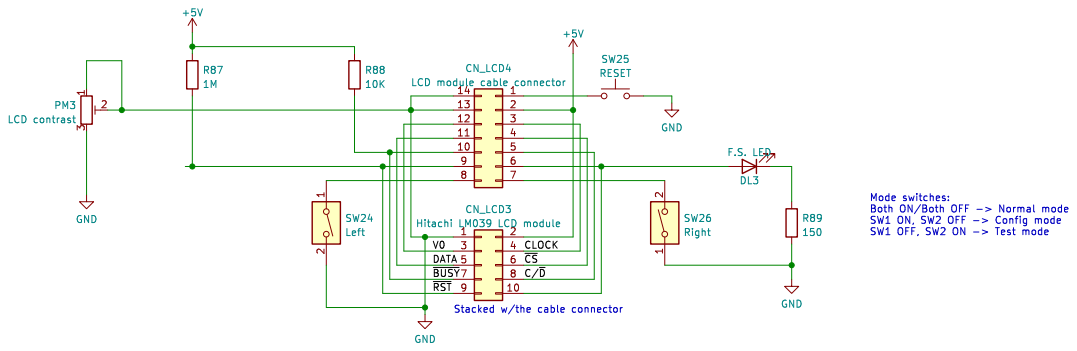
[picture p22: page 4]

LCD module cable connector 1

11 | 4
10 | 5

9CN_LCD3 Hitachi LM039 LCD module GND

Id: 4/12 Title: File: lcd.kicad_sch Sheet: /LCD_board/ GND

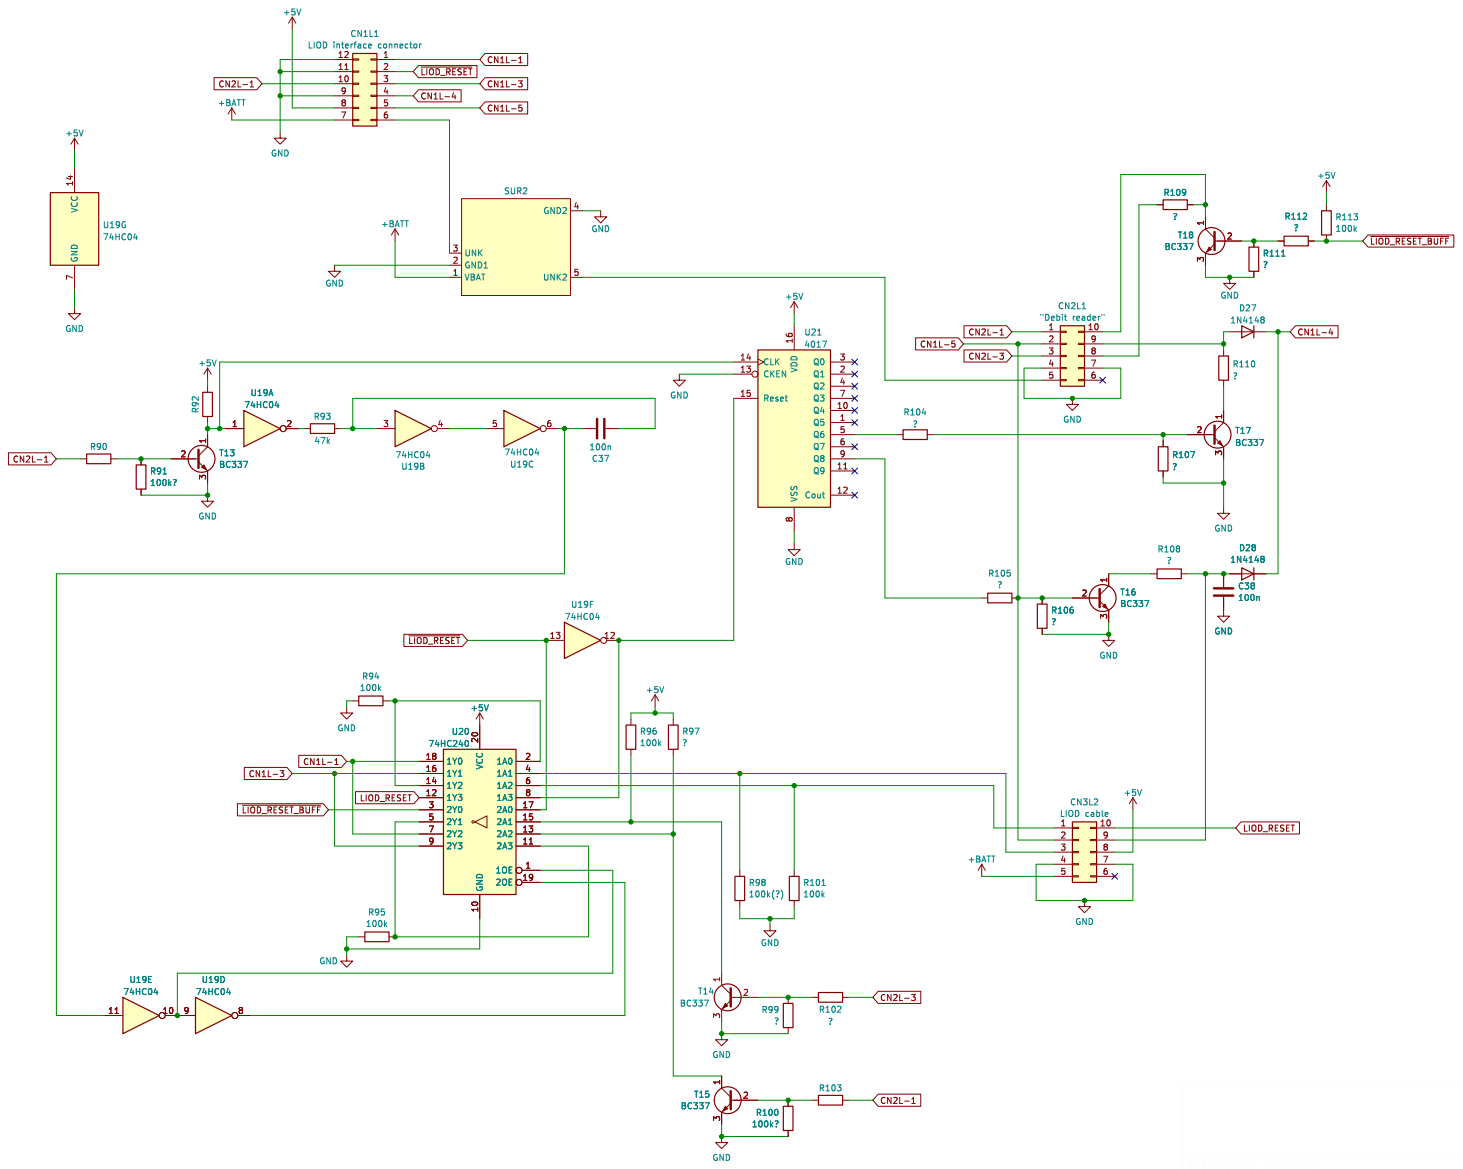
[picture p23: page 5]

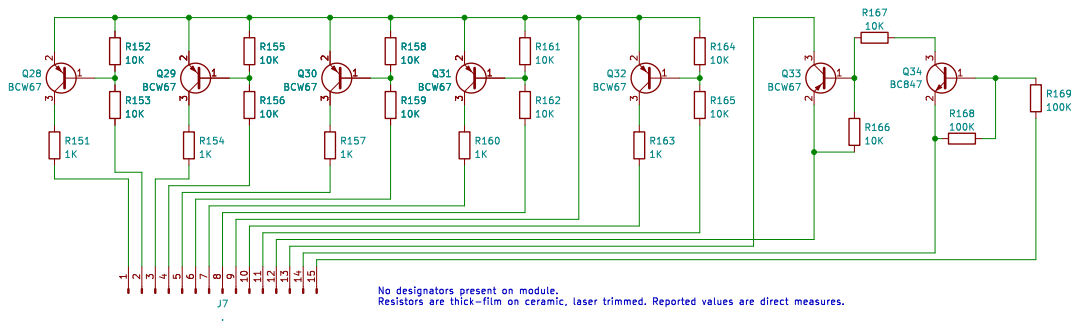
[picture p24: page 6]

Id: 6/12 Title: File: modules_67475.kicad_sch Sheet: /67475/

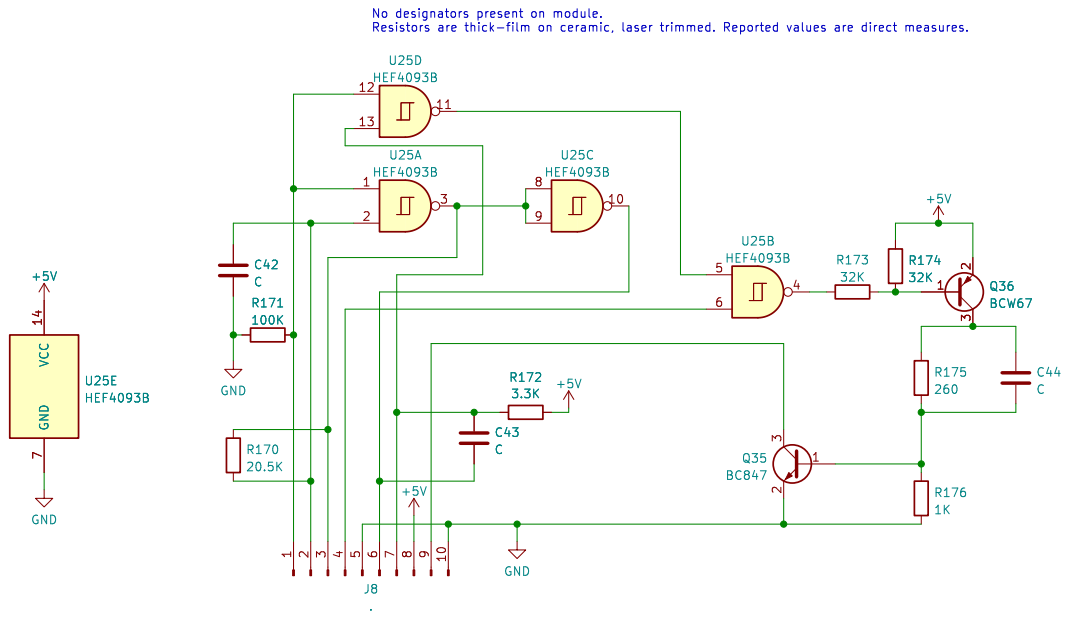
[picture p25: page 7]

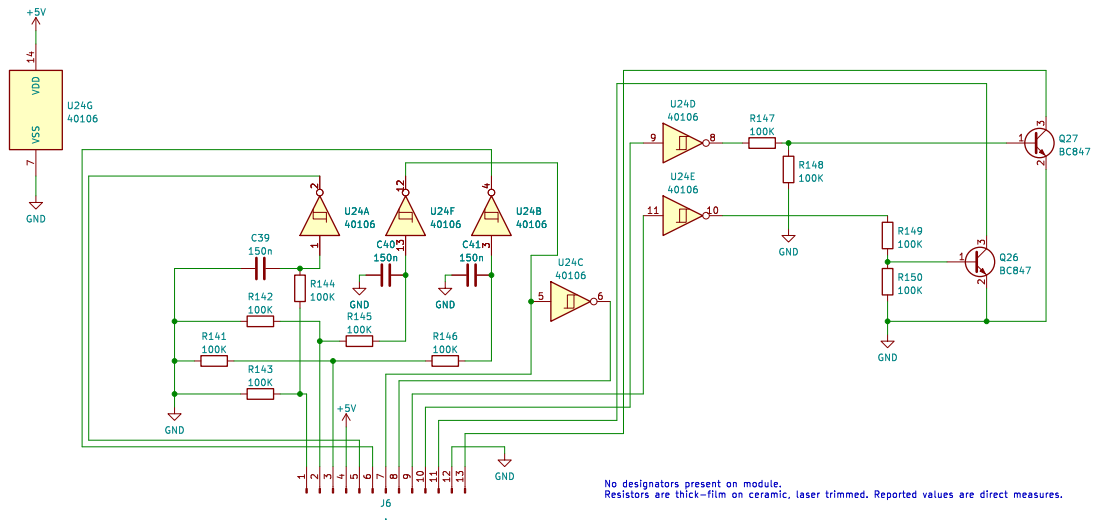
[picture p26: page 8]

Id: 8/12 Title: File: modules_67381.kicad_sch Sheet: /67381/ R144

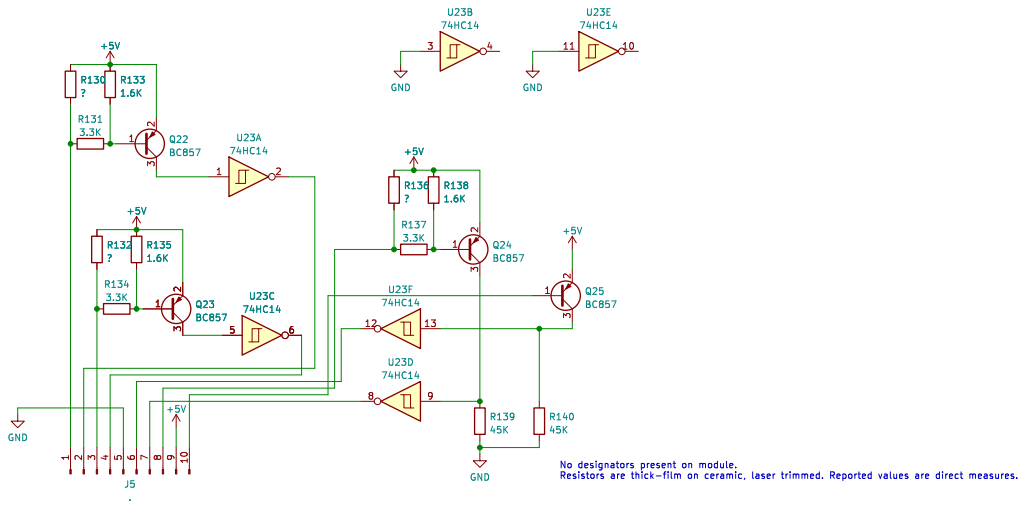
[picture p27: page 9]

Id: 9/12 Title: File: modules_67382.kicad_sch Sheet: /67382/

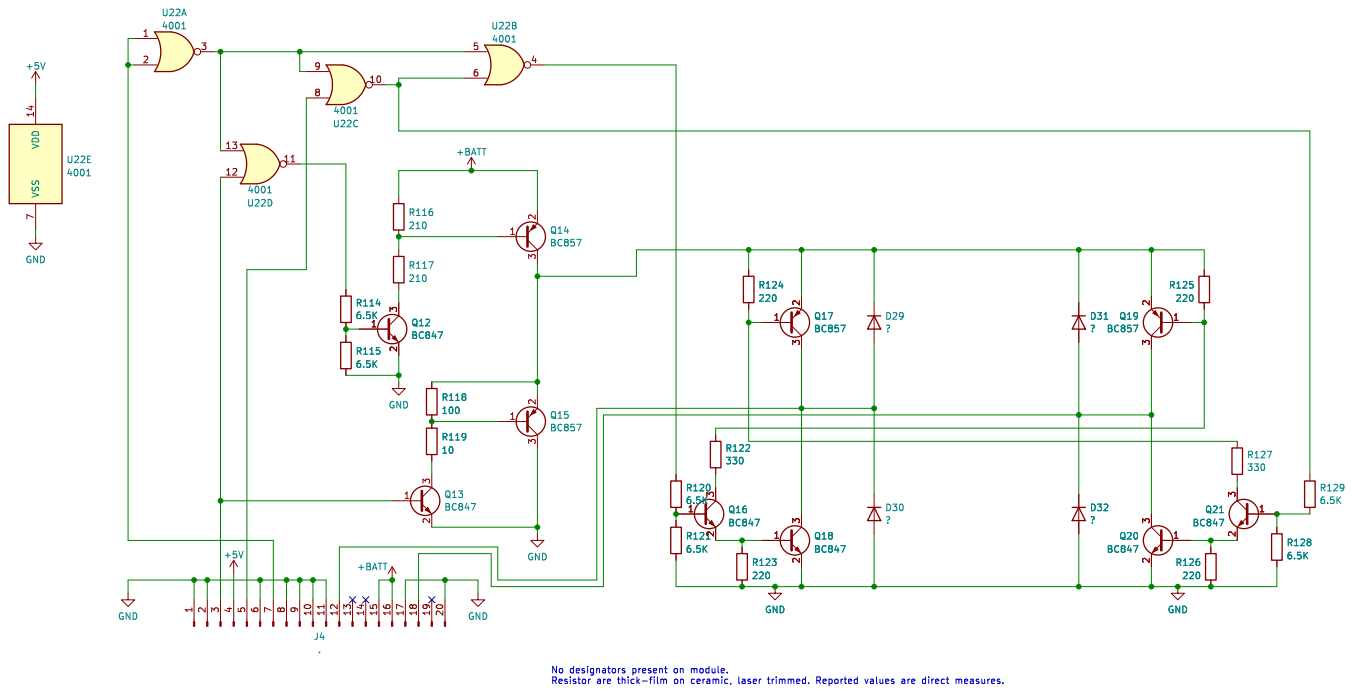
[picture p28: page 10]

Id: 10/12 Title: File: modules_67384.kicad_sch Sheet: /67384/ VDD 14 VSS

2 3 Q15 BC857 No designators present on module. Resistor are thick-film on ceramic, laser trimmed. Reported values are direct measures. GND


Id: 11/12 Title: File: modules_67476.kicad_sch Sheet: /67476/


67475 PNP CE driver OUT

100k 67475 PNP CE driver OUT

-2 M2 Rotor motor Vdd 16 Vss 8 ~{Q2} 10 ~{Q1} 11 ~{Q0} 12 A1

LCD module cable connector
~{RST} LCD_CLK

4 OPT5 Rotor pocket exit photointerrupter

OPT5 Rotor pocket exit photointerrupter 1

"Rotor pocket open" photointerrupter

coin box or to the coin return tray

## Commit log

2022-10-19 First commit A
    [RAM.sch, RotorPSU.sch, cpu.sch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]
2023-05-10 new schmatics
    [main.kicad_sch]
2023-05-10 updated schematics
    [LIOD_interface.kicad_sch, Rotor_kicad.kicad_pcb, Rotor_kicad.kicad_sch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]
2023-12-10 New schematics!
    [8051_plugin_module_LIOD.kicad_sch, LIOD_hybrid.kicad_sch, LIOD_interface.kicad_sch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]
2023-12-12 Fixed some errors on the main board schematic
    [Rotor_kicad.kicad_sch]
2023-12-12 Fixed a minor issue with the LIOD schematic
    [Rotor_LIOD.kicad_sch]
2024-04-11 Fixed minor mistakes in the schematics
    [LIOD_interface.kicad_sch, Rotor_kicad.kicad_sch, frontpanel.kicad_sch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]
2024-04-26 Fixed mistakes in main board schematics
    [LIOD_interface.kicad_sch, Rotor_kicad.kicad_sch, frontpanel.kicad_sch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]
2024-05-20 Schematics update
    [Rotor_kicad.kicad_sch]
2024-08-28 Updated the Line Interface card schematic: fixed mistakes on front panel connections, added some info about the external safe connector
    [LIOD_interface.kicad_sch, Rotor_kicad.kicad_sch, frontpanel.kicad_sch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]
2025-03-18 Fixed the Hitachi processor module; now it's basically the Motorola 6805 module with the necessary modifications to adapt it to the 6305Y2 microcontroller (which has an HC05 core)
2025-06-18 Added PDF schematics
2025-06-18 Added LIOD PDF schematics
2025-06-18 Fixed PDF for LIOD schematics
2026-08-23 Aggiunti schemi completi Rotor OV 1991 nella sezione "manual" Added full schematics for the Rotor OV boards (1991 revision) under the "manual" folder
